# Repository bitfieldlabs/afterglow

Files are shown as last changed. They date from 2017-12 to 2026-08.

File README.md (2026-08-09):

afterglow Afterglow

AFTERGLOW is a pinball machine extension board that aims at softening the hard lamp on/off transitions which are the consequence of replacing the original incandescent bulbs with LEDs. Reproducing the original light effects is a big part of preserving a pinball game's nostalgia.

It currently works with Williams WPC, Williams System 11, Data East and probably also with Sega games. The basic principle involves resampling of the original lamp matrix signals at a higher frequency. This allows for PWM LED dimming with additional brightness steps.

The resampled signal is output via MOSFETs, allowing for direct connection of your pinball machine's lamp matrix.

Make sure to check the wiki for detailed information and instructions.

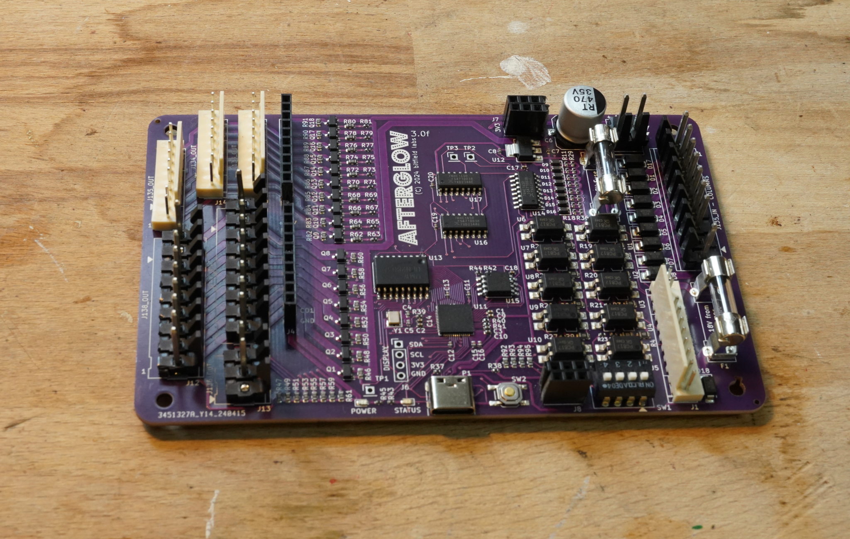
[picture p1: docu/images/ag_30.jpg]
afterglow Afterglow PCB v3.0


While the effect is hard to catch on camera, this video gives an idea:

https://github.com/bitfieldlabs/afterglow/assets/999857/57093b11-0a40-46fb-a978-5d42df743db6

## Licensing

Firmware and configuration software:
Apache License 2.0

Hardware designs:
CERN Open Hardware License - Permissive 2.0

See LICENSES/ for details

### Licensing change

As of August 2026:

- Firmware and configuration software are licensed under Apache-2.0.
- Hardware designs are licensed under CERN-OHL-P-2.0.

All contributors with copyrightable contributions
have consented to the relicensing, or their
contributions have been replaced.

### Quick guide to the board revisions

#### All in one
* *PCB v3.0*<br/>This is the newest board built around the RP2040. Supports WPC, Data East, Sys11, Whitestar, S.A.M.<br/>Supports hats, allowing for different ouput connectors, modding ports, displays etc.<br/>Input protection using optocouplers.<br/>Check the [folder's readme](https://github.com/bitfieldlabs/afterglow/tree/master/afterglow_pcb_v30) for more details.

#### WPC, WPC-95, System 11, Data East, Sega
* *PCB v1.3*<br/>This is the *preferred board revision* for these games.<br/>Dedicated power input (+18V, Ground) must be connected separately to power driver board
* *PCB v1.4*<br/>Except for power input exactly the same as revision 1.3<br/>+18V taken from column input.<br/>⚠ Ground must still be connected to the PDB! Failure to do so will damage the board!
* *PCB v1.5*<br/>Same as v1.4, but using a one-sided PCB. This should be easier/cheaper for automated production than v1.4.

#### Stern Whitestar (and possibly S.A.M.)
* *PCB v2.1* Dedicated board which will only work with Stern Whitestar and possibly S.A.M. games

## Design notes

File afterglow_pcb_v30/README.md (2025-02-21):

# Afterglow PCB v3.0

This is the newest generation of afterglow boards for the switched playfield lamps (not the GI), supporting WPC, Data East, System 11 and Stern Whitestar/S.A.M. games.

## What's new

The new board is based on the RP2040 microprocessor. It is more robust than previous versions and it supports hats!

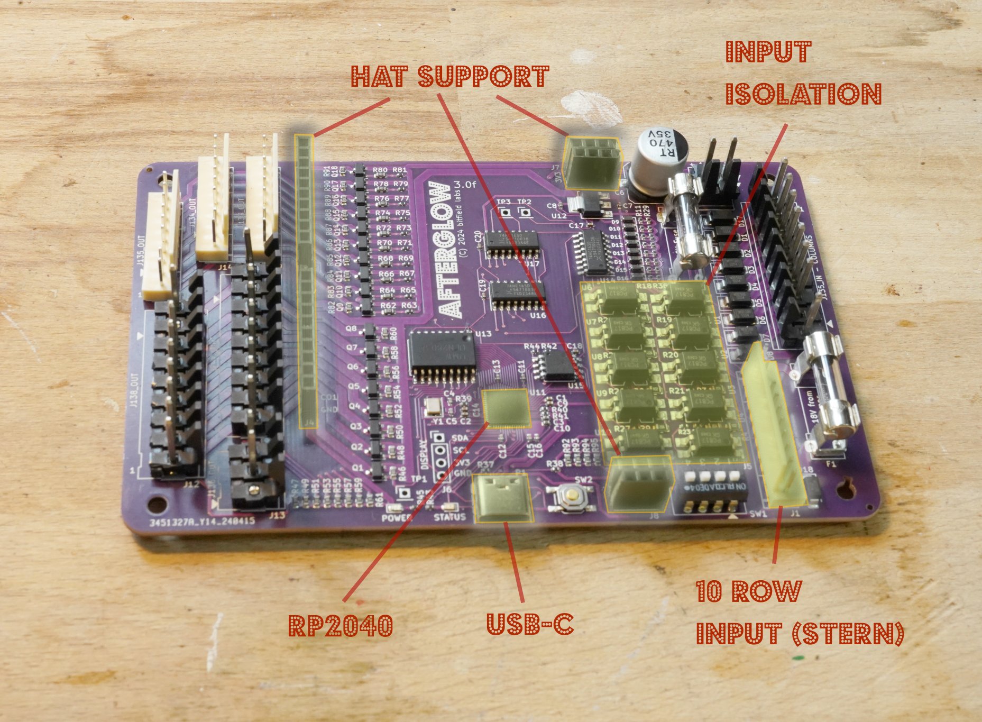
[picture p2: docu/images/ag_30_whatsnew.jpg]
afterglow Afterglow PCB v3.0 What's New


## Production
This board is designed for automated PCB production and assembly. The [gerber directory](https://github.com/bitfieldlabs/afterglow/tree/master/afterglow_pcb_v30/gerber) contains production files for [JLCPCB](https://jlcpcb.com/).

Components were chosen based on availability and price.

The connectors and some other parts are currently not included in the assembly files.

## Firmware
The RP2040 firmare is available in the [afterglow_rp2040_firmware](https://github.com/bitfieldlabs/afterglow/tree/master/afterglow_rp2040_firmware) directory. 

### Building the firmware
The firmware is built using [Visual Studio Code](https://code.visualstudio.com/) with [platformio](https://platformio.org/). You may need to install the wizio library manually (PIO Home->Advanced Installation, enter https://github.com/maxgerhardt/wizio-pico).
It uses [wizio-pico](https://github.com/maxgerhardt/wizio-pico) as a baremetal framework.

### Updating the firmware
There is also a [prebuilt binary UF2 file](https://github.com/bitfieldlabs/afterglow/tree/master/afterglow_rp2040_firmware/firmware_binary_uf2) available for direct upload to the chip. Push the boot select button SW2 when powering up and a mass storage device should appear on your computer. Just copy over the firmware uf2 file.

## Hats
The board supports the connection of hats, extending the functionality to other games, for debugging, modding etc.

### The debugger's hat
The [debugger's hat PCB project](https://github.com/bitfieldlabs/afterglow/tree/master/afterglow_pcb_v30/hat_debug) just visualizes the lamp matrix with LEDs and adds a connector for an I2C OLED display.

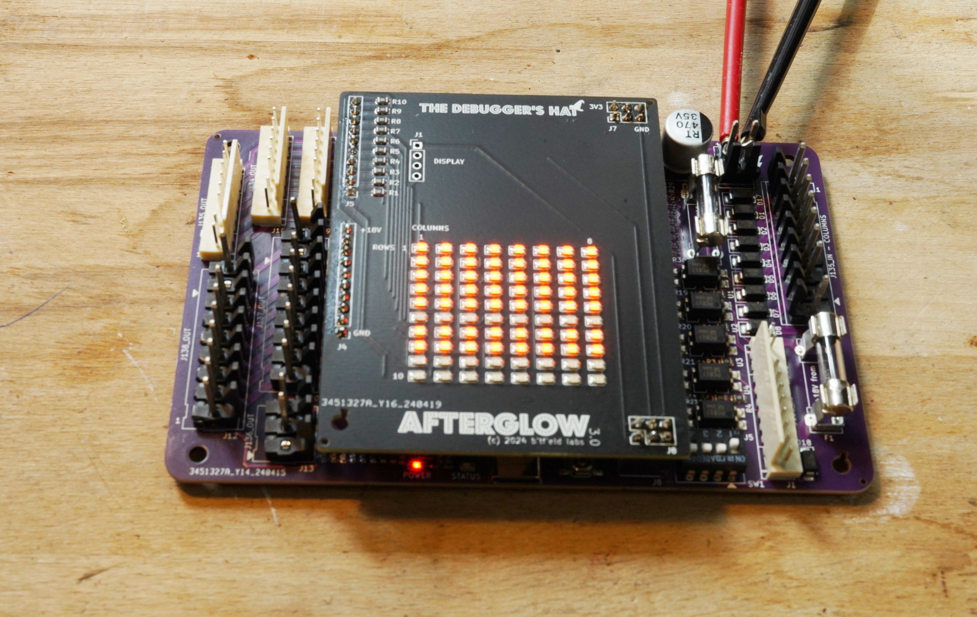
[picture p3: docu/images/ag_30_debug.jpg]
afterglow Afterglow PCB v3.0 Debugger's hat


### The pin bender hat
The [pin bender hat](https://github.com/bitfieldlabs/afterglow/tree/master/afterglow_pcb_v30/hat_stern_de_sys11) adds connectors for direct hookup of Stern Whitestar/S.A.M games as well as Data East and System 11 machines.

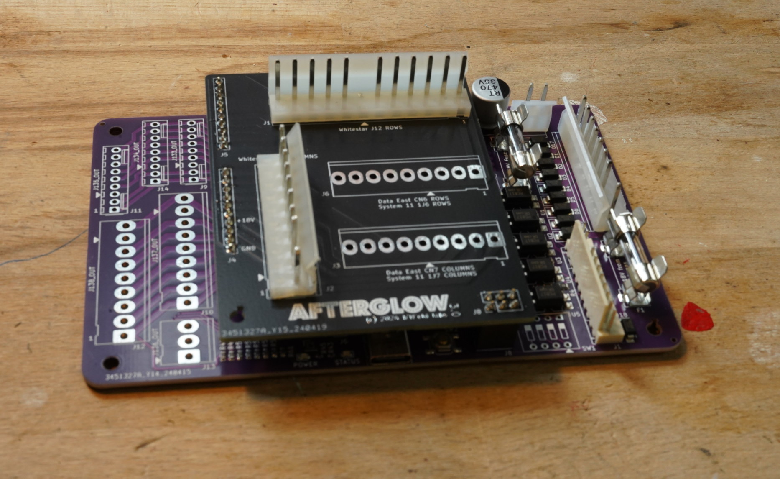
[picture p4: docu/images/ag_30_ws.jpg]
afterglow Afterglow PCB v3.0 Pin Bender hat


### Creating new hats
There is a [template kicad project](https://github.com/bitfieldlabs/afterglow/tree/master/afterglow_pcb_v30/hat_template) which can be used as a starting point for new hats.

## Files

* Schematic Afterglow PCB v3.0 Schematic
* BOM Afterglow PCB v3.0 BOM

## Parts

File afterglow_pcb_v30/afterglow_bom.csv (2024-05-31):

Reference | Value | Datasheet | Footprint | Qty | DNP
C1,C2,C9,C11,C12,C13,C14,C15,C16,C17,C19,C20,C21 | 100n | ~ | Capacitor_SMD:C_0402_1005Metric | 13
C3,C10 | 1u | ~ | Capacitor_SMD:C_0402_1005Metric | 2
C4,C5 | 22p | ~ | Capacitor_SMD:C_0402_1005Metric | 2
C6 | 470uF | ~ | Capacitor_SMD:C_Elec_10x10.2 | 1
C7,C8 | 1uF |  | Capacitor_SMD:C_0402_1005Metric | 2
C18 | 0.1 |  | Capacitor_SMD:C_0402_1005Metric | 1
D1,D2,D3,D4,D5,D6,D7,D8,D17,D18 | RB080 | ~ | Diode_SMD:D_SMA | 10
D9,D10,D11,D12,D13,D14,D15,D16 | 3.0V | ~ | Diode_SMD:D_SOD-323 | 8
F1,F2 | 5A SB |  | Fuse:Fuseholder_Clip-5x20mm_Schurter_OG_Lateral_P15.00x5.00mm_D1.3mm_Horizontal | 2
J1 | J133_IN_R | ~ | Connector_Molex:Molex_KK-254_AE-6410-11A_1x11_P2.54mm_Vertical | 1
J2 | J137_IN_C |  | Connector_Molex:Molex_KK-396_5273-09A_1x09_P3.96mm_Vertical | 1
J3 | Conn_Power | ~ | Connector_Molex:Molex_KK-396_5273-02A_1x02_P3.96mm_Vertical | 1
J4,J5 | Conn_01x10_Pin | ~ | Connector_PinSocket_2.54mm:PinSocket_1x10_P2.54mm_Vertical | 2
J6 | Conn_01x04_Socket | ~ | Connector_PinHeader_2.54mm:PinHeader_1x04_P2.54mm_Vertical | 1
J7,J8 | Conn_02x03_Odd_Even | ~ | Connector_PinSocket_2.54mm:PinSocket_2x03_P2.54mm_Vertical | 2
J9 | J133_OUT_R |  | Connector_Molex:Molex_KK-254_AE-6410-09A_1x09_P2.54mm_Vertical | 1
J10 | J137_OUT_C |  | Connector_Molex:Molex_KK-396_5273-09A_1x09_P3.96mm_Vertical | 1
J11 | J134_OUT_R |  | Connector_Molex:Molex_KK-254_AE-6410-09A_1x09_P2.54mm_Vertical | 1
J12 | J138_OUT_C |  | Connector_Molex:Molex_KK-396_5273-09A_1x09_P3.96mm_Vertical | 1
J13 | 136_OUT_C |  | Connector_Molex:Molex_KK-396_5273-03A_1x03_P3.96mm_Vertical | 1
J14 | J135_OUT_R |  | Connector_Molex:Molex_KK-254_AE-6410-09A_1x09_P2.54mm_Vertical | 1
P1 | USB_C_Receptacle_USB2.0_14P | https://www.usb.org/sites/default/files/documents/usb_type-c.zip | Connector_USB:USB_C_Receptacle_HRO_TYPE-C-31-M-12 | 1
PWR_LED1,ST_LED1 | LED | ~ | LED_SMD:LED_0603_1608Metric | 2
Q1,Q2,Q3,Q4,Q5,Q6,Q7,Q8 | AO3401A | http://www.aosmd.com/pdfs/datasheet/AO3401A.pdf | Package_TO_SOT_SMD:SOT-23 | 8
Q9,Q10,Q11,Q12,Q13,Q14,Q15,Q16,Q17,Q18 | AO3400A | http://www.aosmd.com/pdfs/datasheet/AO3400A.pdf | Package_TO_SOT_SMD:SOT-23 | 10
R1,R2,R3,R4,R5,R6,R7,R8,R9,R10,R11,R12,R13,R14,R15,R16,R17,R18,R19,R20,R21,R22,R23,R24,R25,R26,R27,R28,R29,R30,R31,R32,R33,R34,R35,R36,R39,R42,R43,R45 | 1k | -- mixed values -- | -- mixed values -- | 40
R37,R38 | 5k1 | ~ | Resistor_SMD:R_0402_1005Metric | 2
R40,R41 | 27 | ~ | Resistor_SMD:R_0402_1005Metric | 2
R44,R47,R49,R51,R53,R55,R57,R59,R61,R63,R65,R67,R69,R71,R73,R75,R77,R79,R81,R82,R83,R84,R85,R86,R87,R88,R89,R90,R91,R92,R93,R94,R95 | 10k | -- mixed values -- | -- mixed values -- | 33
R46,R48,R50,R52,R54,R56,R58,R60 | 2k |  | Resistor_SMD:R_0603_1608Metric | 8
R62,R64,R66,R68,R70,R72,R74,R76,R78,R80 | 220 |  | Resistor_SMD:R_0603_1608Metric | 10
R96 | 200mOhm | ~ | Resistor_SMD:R_2512_6332Metric | 1
SW1 | CFG |  | Button_Switch_THT:SW_DIP_SPSTx04_Slide_9.78x12.34mm_W7.62mm_P2.54mm | 1
SW2 | SW_Push | ~ | Button_Switch_SMD:SW_SPST_SKQG_WithStem | 1
TP1,TP2,TP3 | TestPoint | ~ | Connector_PinHeader_2.54mm:PinHeader_1x01_P2.54mm_Vertical | 3
U1,U2,U3,U4,U5,U6,U7,U8,U9,U10 | PC817 | http://www.soselectronic.cz/a_info/resource/d/pc817.pdf | Package_DIP:SMDIP-4_W9.53mm | 10
U11 | RP2040 |  | Package_DFN_QFN:QFN-56-1EP_7x7mm_P0.4mm_EP3.2x3.2mm_ThermalVias | 1
U12 | NCP1117-3.3_SOT223 | http://www.onsemi.com/pub_link/Collateral/NCP1117-D.PDF | Package_TO_SOT_SMD:SOT-223-3_TabPin2 | 1
U13 | ULN2803A |  | Package_SO:SOIC-18W_7.5x11.6mm_P1.27mm | 1
U14,U16,U17 | 74LS165 |  | Package_SO:SOIC-16_3.9x9.9mm_P1.27mm | 3
U15 | W25Q32JVSS | http://www.winbond.com/resource-files/w25q32jv%20revg%2003272018%20plus.pdf | Package_SO:SOIC-8_5.23x5.23mm_P1.27mm | 1
U18 | INA181A1 | http://www.ti.com/lit/ds/symlink/ina181.pdf | Package_TO_SOT_SMD:SOT-23-6 | 1
Y1 | Crystal_GND24_Small | ~ | Crystal:Crystal_SMD_3225-4Pin_3.2x2.5mm | 1

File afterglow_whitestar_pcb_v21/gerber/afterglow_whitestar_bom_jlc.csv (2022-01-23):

Comment | Designator | Footprint | LCSC Part #
0.33 | C2 | C_0805_2012Metric_Pad1.18x1.45mm_HandSolder | C1740
0.1 | C3,C4,C5 | C_0805_2012Metric_Pad1.18x1.45mm_HandSolder | C28233
WS2812B | D1 | LED_WS2812B-PLCC4 | C2761795
4.7V | D2,D3,D4,D5,D6,D7,D8,D9 | D_SOD-323_HandSoldering | C391551
1k | R1,R2,R3,R4,R5,R6,R7,R8,R9,R10,R11,R12,R13,R14,R15,R16,R17,R18,R19,R20,R21,R22,R23,R24 | R_0805_HandSoldering | C95781
10k | R25,R27,R28,R29,R30,R31,R32,R33,R34,R44,R46,R48,R50,R52,R54,R56,R58,R59,R60,R61,R62,R63,R64,R65,R66,R67,R69,R70,R71 | R_0805_HandSoldering | C84376
220 | R26,R43,R45,R47,R49,R51,R53,R55,R57,R68 | R_0805_HandSoldering | C17557
2k | R35,R36,R37,R38,R39,R40,R41,R42 | R_0805_HandSoldering | C17604
74LS165 | U1,U2 | SOIC-16_3.9x9.9mm_Pitch1.27mm | C5613
74HC595 | U5,U6 | SOIC-16_3.9x9.9mm_Pitch1.27mm | C5947
ULN2803A | U7 | SOIC-18W_7.5x11.6mm_Pitch1.27mm | C845537

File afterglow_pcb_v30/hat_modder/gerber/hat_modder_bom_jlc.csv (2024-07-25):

Comment | Designator | Footprint | LCSC Part Number
LED | D1,D2,D3,D4 | LED_0805_2012Metric | C2296
Conn_02x03_Odd_Even | J2,J3 | PinHeader_2x03_P2.54mm_Vertical | C92272
1k | R1,R6,R7,R8,R9 | R_0805_2012Metric | C17513
220 | R2,R3,R4,R5 | R_0805_2012Metric | C17557
74HC244 | U1 | TSSOP-20_4.4x6.5mm_P0.65mm | C6835
74HC595 | U2 | SO-16_3.9x9.9mm_P1.27mm | C5947
PC817 | U3,U4,U5,U6 | SMDIP-4_W9.53mm | C3025164

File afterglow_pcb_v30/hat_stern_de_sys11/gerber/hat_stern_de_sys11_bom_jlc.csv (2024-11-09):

Comment | Designator | Footprint | LCSC Part Number
ROW OUT | J1 | Molex_KK-396_5273-12A_1x12_P3.96mm_Vertical | C10589
COLUMN OUT | J2 | Molex_KK-396_5273-10A_1x10_P3.96mm_Vertical | C10587
Conn_01x09_Pin | J3,J6 | Molex_KK-396_5273-09A_1x09_P3.96mm_Vertical | C10586
Conn_01x10_Pin | J4,J5 | PinHeader_1x10_P2.54mm_Vertical | C5156617
Conn_02x03_Odd_Even | J7,J8 | PinHeader_2x03_P2.54mm_Vertical | C18905882

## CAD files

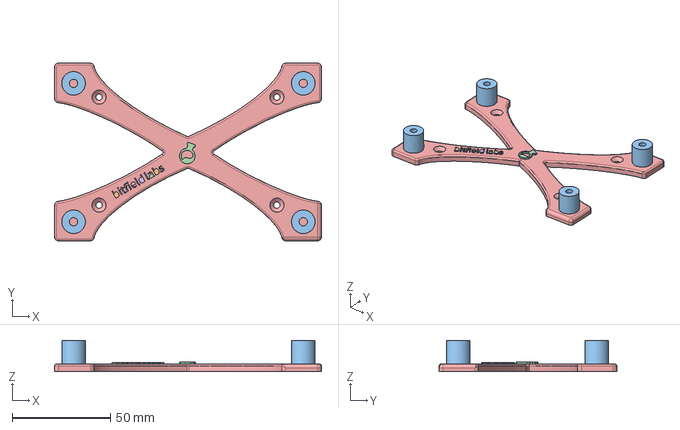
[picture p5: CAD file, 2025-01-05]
accessories/ag_14_to_30_holder_generic_insert_higher.step
136.0 x 90.5 x 16.0 mm

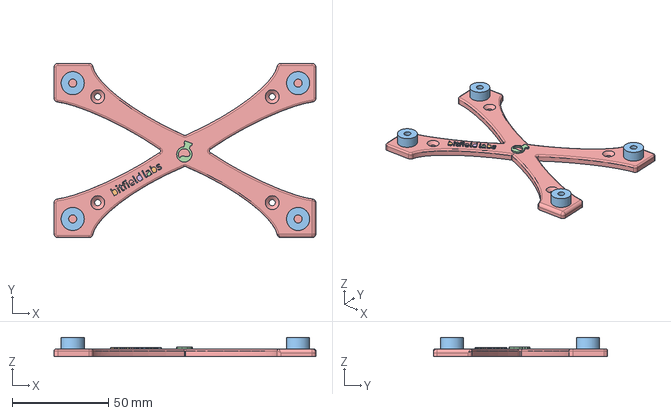
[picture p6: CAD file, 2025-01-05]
accessories/ag_14_to_30_holder_generic_insert.step
136.0 x 90.5 x 10.0 mm

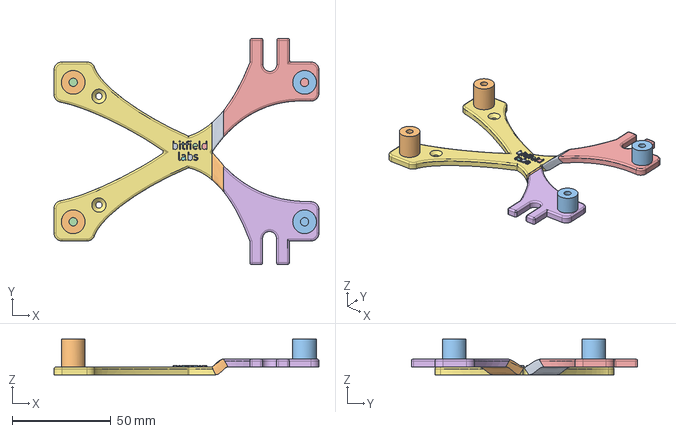
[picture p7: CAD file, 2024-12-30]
accessories/ag_14_to_30_holder_wpc_insert.step
134.0 x 114.5 x 18.0 mm

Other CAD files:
accessories/ag_14_to_30_holder_generic_screw_higher.step
accessories/ag_14_to_30_holder_generic_screw.step
accessories/ag_14_to_30_holder_wpc_screw.step
accessories/ag_14_to_30_holder_generic_insert.stl
accessories/ag_14_to_30_holder_generic_insert_higher.stl
accessories/ag_14_to_30_holder_generic_screw.stl
accessories/ag_14_to_30_holder_generic_screw_higher.stl
accessories/ag_14_to_30_holder_wpc_insert.stl
accessories/ag_14_to_30_holder_wpc_screw.stl

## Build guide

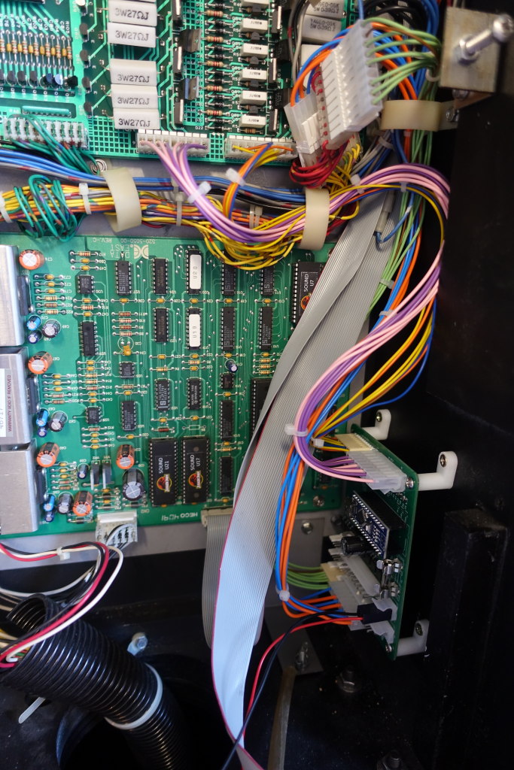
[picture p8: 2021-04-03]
docu/images/data_east_installation_2.jpg

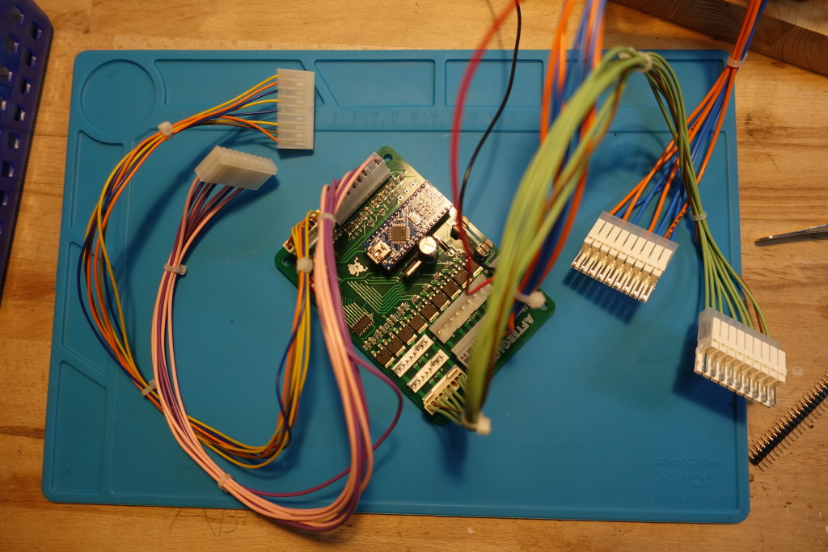
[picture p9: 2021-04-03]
docu/images/data_east_installation_1.jpg

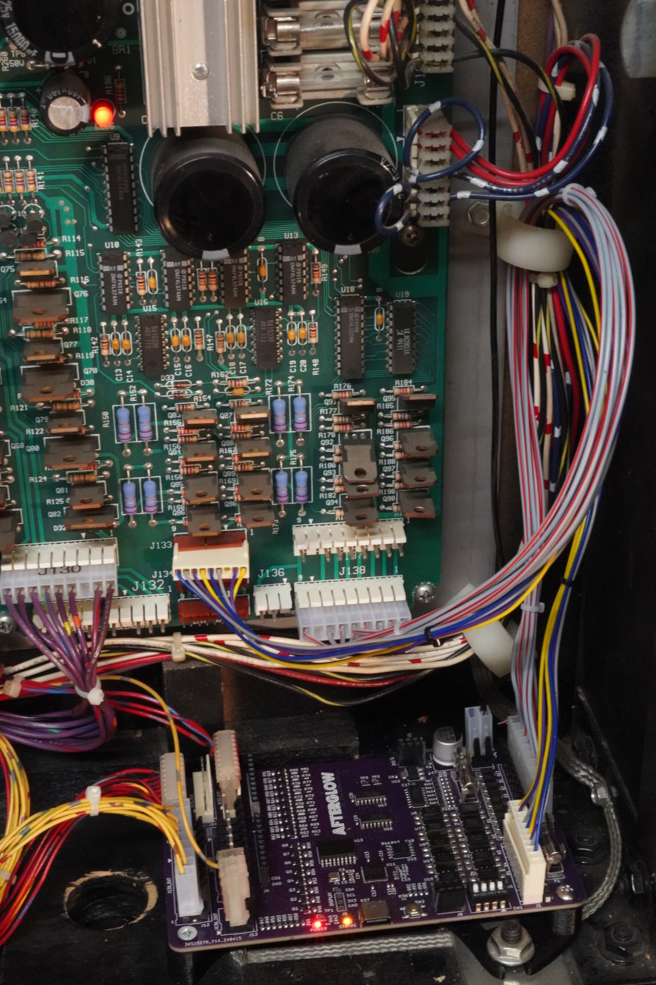
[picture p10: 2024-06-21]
docu/images/ag_30_installed_wpc.jpg

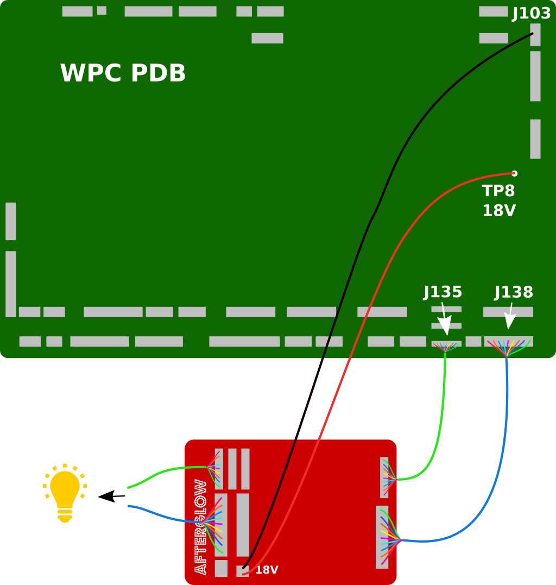
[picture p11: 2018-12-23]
docu/afterglow_installation.png

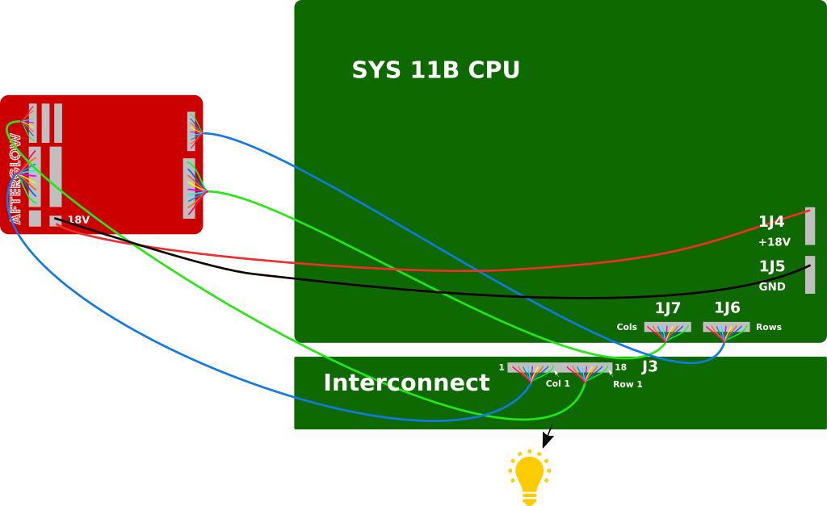
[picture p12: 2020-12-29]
docu/afterglow_installation_sys11.png

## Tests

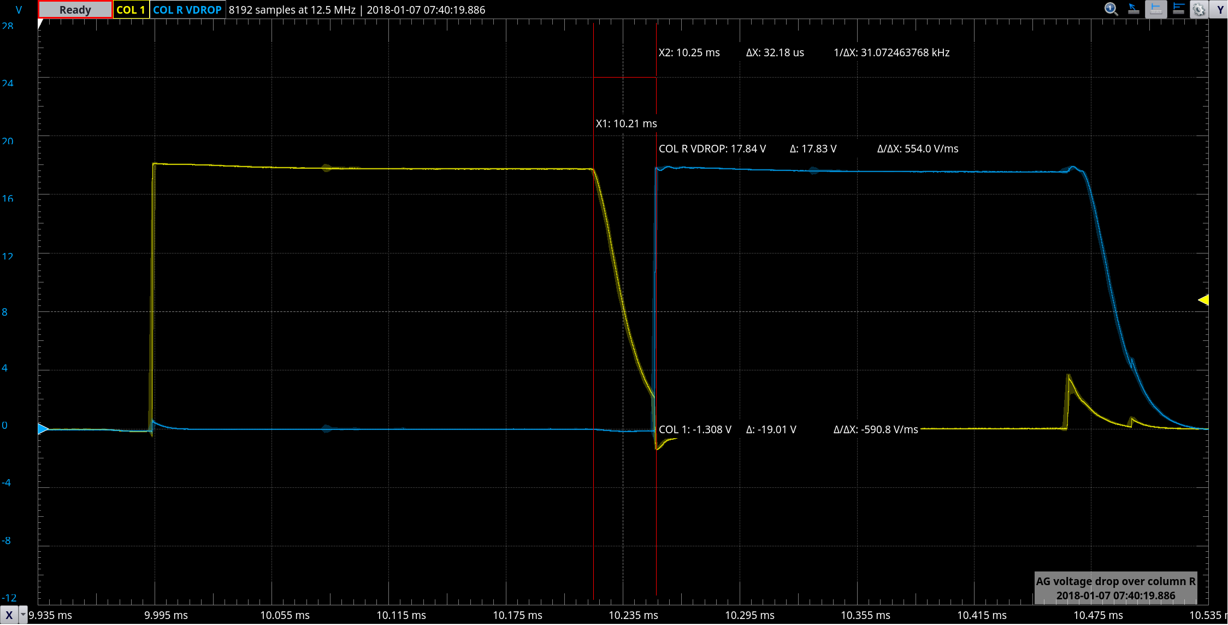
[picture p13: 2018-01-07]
scopes/AG/col1_col2_col2_testmode.png

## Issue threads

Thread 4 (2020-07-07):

STM32 Version

madnat, 2020-07-07:
Hi there - enjoyed following your work on Afterglow and AGGI.

Is there a technical reason for splitting the LED functions between 2 different boards?  I assume it is a speed issue for the Arduino Nano?

Discussing with Stumblor, interested to see if creating a STM32 version of this could enable a combined board to manage all LED's on a machine?  STM32 is technically a more superior processor (in every way I think?), and should run the same code as an Arduino.  It is also more power efficient I believe.

I have started to map your schematic of Afterglow to a STM32 version (I use Eagle however), very happy to publish to a new fork - if it would be helpful to work on this together?

With a more powerful processor the scope for extending capability, e.g. support additional addressable LED strings could be very cool (i.e. support SK6812 controllers - sync lighting or trigger new light effect based existing lamp events).

Could be getting crazy here - but also thought adding a WiFi module would then enable configuration on the fly rather than an external app.  No doubt that would need some additional memory/SD.  We could learn a lot from the PIN2DMD project.

Hope these suggestions/offer is helpful

Closed 2021-01-02.

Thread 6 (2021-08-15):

add game jokerz sys11b

ledu205, 2021-08-15:
[games.zip](https://github.com/bitfieldlabs/afterglow/files/6988503/games.zip)

config for jokerz pinball work good with pcb 1.4

bitfieldlabs, 2021-08-16:
Tanks! Pushed to repository.

Closed 2021-08-16.

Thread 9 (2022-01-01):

Errors on 1.4 PCB

JustinRudebaugh, 2022-01-01:
First off - Excellent project! I've been reading through everything I can here and on pinball forums.  I've ordered a batch of these to assemble and found a couple issues, and a question after exporting the BOM via KiCAD (for use with Partsbox).

-R67 is listed as "18v COL".  I see note in wiki about the 18V columns, but would this be a jumper or resistor in the R67 position? If it's a resistor, what's the value?
-J1 is listed in BOM as J137_IN_C, but silkscreen is J138_IN_C
-J2 is listed in BOM as J133_IN_R, but silkscreen is J135_IN_R
-D1, D10, D11, D12, D13, D14, D15, D16, and D17 is not on the silkscreen

Thank you!

bitfieldlabs, 2022-01-01:
Thanks for the feedback. I will need to make adjustments to the BOM later.

R67 is a zero Ohm resistor. It can be populated as a wire bridge. It is only needed when feeding the +18V from the columns and can be left unpopulated when supplying +18V via J3.

J137 and J138 are connected to the same lines. The same is true for the J133, J134 and J135 connectors. The labels are used a bit inconsistently in the schematic and silkscreen. On the silkscreen I wanted to make clear where to connect to easiest.

Somehow my Kicad footprint for the Schottky diodes doesn't have a proper silkscreen layer. I need to fix that.

Be also aware that I've had several reports of damaged v1.4 boards when people forgot to connect the ground line. It's a design flaw of this +18V from columns design. Personally I prefer the v1.3 board as I also don't mind connecting both +18V and GND to the PPD.

bitfieldlabs, 2022-01-02:
Fixed silkscreening issues with [5ce20851](https://github.com/bitfieldlabs/afterglow/commit/5ce20851aaa8b1ce0ea9a661658f488daa178507).
R67 documented in BOM.

Closed 2022-01-02.

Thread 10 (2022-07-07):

Afterglow version using atmega328p DIP version

bzhmaddog, 2022-07-07:
Not a bug but I was thinking of using an atmega328p dip chip (the one on the original arduino uno) instead of a nano daughter board.
It is basically the same chip as the one on the nano except for A6 and A7 io missing but thoses are not used on afterglow design af far as I can tell.
The chip would fit in the area where nano goes and just requires a crystal and two caps plus a 2x3 pin header for ICSP programming.

bitfieldlabs, 2022-07-08:
Yes, that is for sure feasible. You will lose the USB interface to the configuration software, but that may not be an issue to many. If the part crisis would allow it, you could also use the small SMD chip.

bzhmaddog, 2022-07-08:
I forked your repository and started working on it (v1.3 for now). I am not a big fan of SMD since it requires extra effort for soldering. As for the usb I will provide an ICSP header which is sure less conveniant than usb but I think people who are ready to flash a sketch file through arduino ide will probably also have some arduino lying around to use as programmer

Closed 2024-02-03.

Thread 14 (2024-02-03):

Wrong label for pin1 of J138

bzhmaddog, 2024-02-03:
The 'documentation' states
Board revision 1.3 has the J138 OUT connector pin 1 labelled on the wrong side! The pin labelled "1" is actually pin 9.

But what is the action required to mitigate the issue ? just swap the connector orrientation  ? or swap the wires on the harness ?

bitfieldlabs, 2024-02-04:
No action needed really. The original J138 connectors can be used. It's just that pin 1 is on the other side of the connector, where it should be. The label is just confusing as it suggests that the connector must be the wrong way round.

bzhmaddog, 2024-02-04:
I see so it is only the label that is wrong but not the traces on the board.

Additionnaly I am wondering why tapping in the 18V to generate the 5V? It is only used to power the Arduino and the few ICs right ? So the LM7805 must be quite hot dropping from 18V to 5V.
Why not using a 12V input ? not enough Amps ? Sorry if it is a dumb question I am not an electronical engineer.

bzhmaddog, 2024-02-04:
I am starting to wonder if that board is compatible with System 11a. The key pins on J6/J7 on my PDB does not match.

https://imgur.com/a/R12S2Hx

bitfieldlabs, 2024-02-04:
The LM7805 doesn't get hot as the 5V side is using only very little power. The 18V are needed to drive the lamp matrix, so it makes sense to use it for the 5V regulator as well.

bitfieldlabs, 2024-02-04:
The board should be fine in Sys11a games, I have personally only tested with Sys11b.
The keys are in a different place than on WPC, you just need to make sure you connect col 1 on the output of the driver board to col 1 on the AG input etc.
https://github.com/bitfieldlabs/afterglow/wiki/Instructions#system-11-installation

bzhmaddog, 2024-02-04:
I see.
My bad I didn't read the schematic correctly. Obviously the 18V is needed since the board hook into the original lines
So I guess I have to make and adapter to make the rows and cols match.

Thx

Closed 2024-02-04.

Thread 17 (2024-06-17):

V3.0 - Fuse holders and J1

vikbez, 2024-06-17:
Hello;

Was about to order the new version to try it :)

I have some questions: I found `J1` to match either:
- [LCSC C22451132](https://www.lcsc.com/product-detail/Wire-To-Board-Connector_DLL-2510-11A_C22451132.html)
- [LCSC C2982040](https://www.lcsc.com/product-detail/Wire-To-Board-Connector_HCTL-HC-2510-11A_C2982040.html)

Are these good candidates ? (only the second one available right now)

For `F1` and `F2` (fuse holders):
I just cannot find them at all. Every part I find are rotated 90deg , or have only 2 pins total:
- [90deg rotated holder](https://i.ebayimg.com/images/g/k7gAAOSw8FBbCToB/s-l1200.jpg)
- [2 pins inline holder](https://www.tancredi.it/55146-large_default/PCB-fuse-holder-for-fuses-5x20mm.jpg)

Maybe these would be more appropriate for the design as they are more easy to find ?

Thanks !

bitfieldlabs, 2024-06-18:
Hi. Yes, the J1 connectors look fine. They are not in the JLC BOM because I couldn't find an exact match for the series I am usually using.

I agree, I will have to change the fuse holders to more common ones, I just didn't get around to doing it yet.

bitfieldlabs, 2024-06-18:
These are the fuse holders I am using: https://jlcpcb.com/partdetail/Schurter-07510062/C3205391
Not on stock though.

Numiah, 2024-11-04:
For the users from Netherlands, Germany etc.
I used these :[https://www.conrad.nl/nl/p/eska-120700-120700-zekeringclip-geschikt-voor-buiszekering-5-x-20-mm-6-3-a-250-v-ac-1-stuk-s-524314.html](url)

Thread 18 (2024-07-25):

Resistor Sizes incorrect in JLCPCB BOM

Nutty-69, 2024-07-25:
Hi

JLCPCB is incorrectly sizing to 0603 in resistor row R63 - R81.

For Example it has row R82 - R91 and R63 - R81

in the same part yet the BOM has it listed separate.

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

Nutty-69, 2024-07-25:
I have found more as below.

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

bitfieldlabs, 2024-07-26:
Not sure I understand. The PCB version 3.0 uses a mix of 0402 and 0603 resistors. E.g., all even numbers between R62-R80 are 0603 resistors while the odd ones are 0402. I see them listed correctly in https://github.com/bitfieldlabs/afterglow/blob/master/afterglow_pcb_v30/gerber/afterglow_bom_jlc.csv...

bitfieldlabs, 2024-07-27:
That's weird as I have used the JLC files in the gerber folder multiple times now without such issues.

Nutty-69, 2024-07-27:
I will try it again tonight :-)

Nutty-69, 2024-07-27:
Ok Same files different outcome !! You got to love JLCPCB sometimes.

But this was easy to sort :-)

Thanks for your help.

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

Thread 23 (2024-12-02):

Leds with AfterGlow board 3.0 and 3.03 firmware

Vincz123, 2024-12-02:
Hello
-Brightness is set to 7, which is the maximum I can get with the board, and it's too dark.
if I remove the Afterglow board, the leds light up twice as much. (leds are 4smd high quality)

On my Medieval or Attack from mars in Attract Mode , the blinking works perfectly but not in the game,  the LED should be flashing but it is not and remains permanently lit.
i can reduce Glow intensity with the software but it's not good

If i compare with OCD , all of my leds is working fine by default

[AFM_MM.zip](https://github.com/user-attachments/files/17981836/AFM_MM.zip)

Thanks if you have any fix

Vincz123, 2024-12-02:
here is a short video in attract mode and when i start a game
[Uploading IMG_1416.zip…]()

Vincz123, 2024-12-02:
[IMG_1416.zip](https://github.com/user-attachments/files/17982011/IMG_1416.zip)
here is a short video in attract mode and when i start a game

bitfieldlabs, 2024-12-02:
Is the AfM recording from attract mode only? Or should I see the in-game issue?

Vincz123, 2024-12-02:
Only attract mode

bitfieldlabs, 2024-12-02:
And the MM recording appears to be empty.

bitfieldlabs, 2024-12-02:
The AfM replay looks nice and bright on my test matrix. But it's of course hard to tell without comparison.

bitfieldlabs, 2024-12-04:
I have tested the board in a Medieval Madness game today and couldn't spot any obvious issues.

Vincz123, 2024-12-04:
With different boards and different pinballs i have this problem.
Which leds did you use? Mine are probably anti ghosting but as i said the same leds on my Lotr and OCD board works fine by default

bitfieldlabs, 2024-12-04:
I don't know what LEDs are in that MM, it wasn't mine. I have tried the board with many different LEDs though, and while you can see some differences in the glow behavior, it's not that big.

bitfieldlabs, 2024-12-04:
I would be really curious to get one of your LEDs for testing, if possible.

bitfieldlabs, 2024-12-09:
Other things to try:
- How is the brightness in pass-through mode (DIP switch 4 on)?
- Supply +18V directly instead taking it from the columns

Vincz123, 2024-12-09:
I use the +18V directly from the driver board at TP102, I've never tried it from the columns.
I'll test DIP4 later

Vincz123, 2024-12-09:
if i only open DIP4 , it's much better for brightness intensity and flashing when I play
What is the difference with DIP4 ?

bitfieldlabs, 2024-12-09:
Pass-through mode replicates the original input signal to the output. It should look like without the AG board inbetween.

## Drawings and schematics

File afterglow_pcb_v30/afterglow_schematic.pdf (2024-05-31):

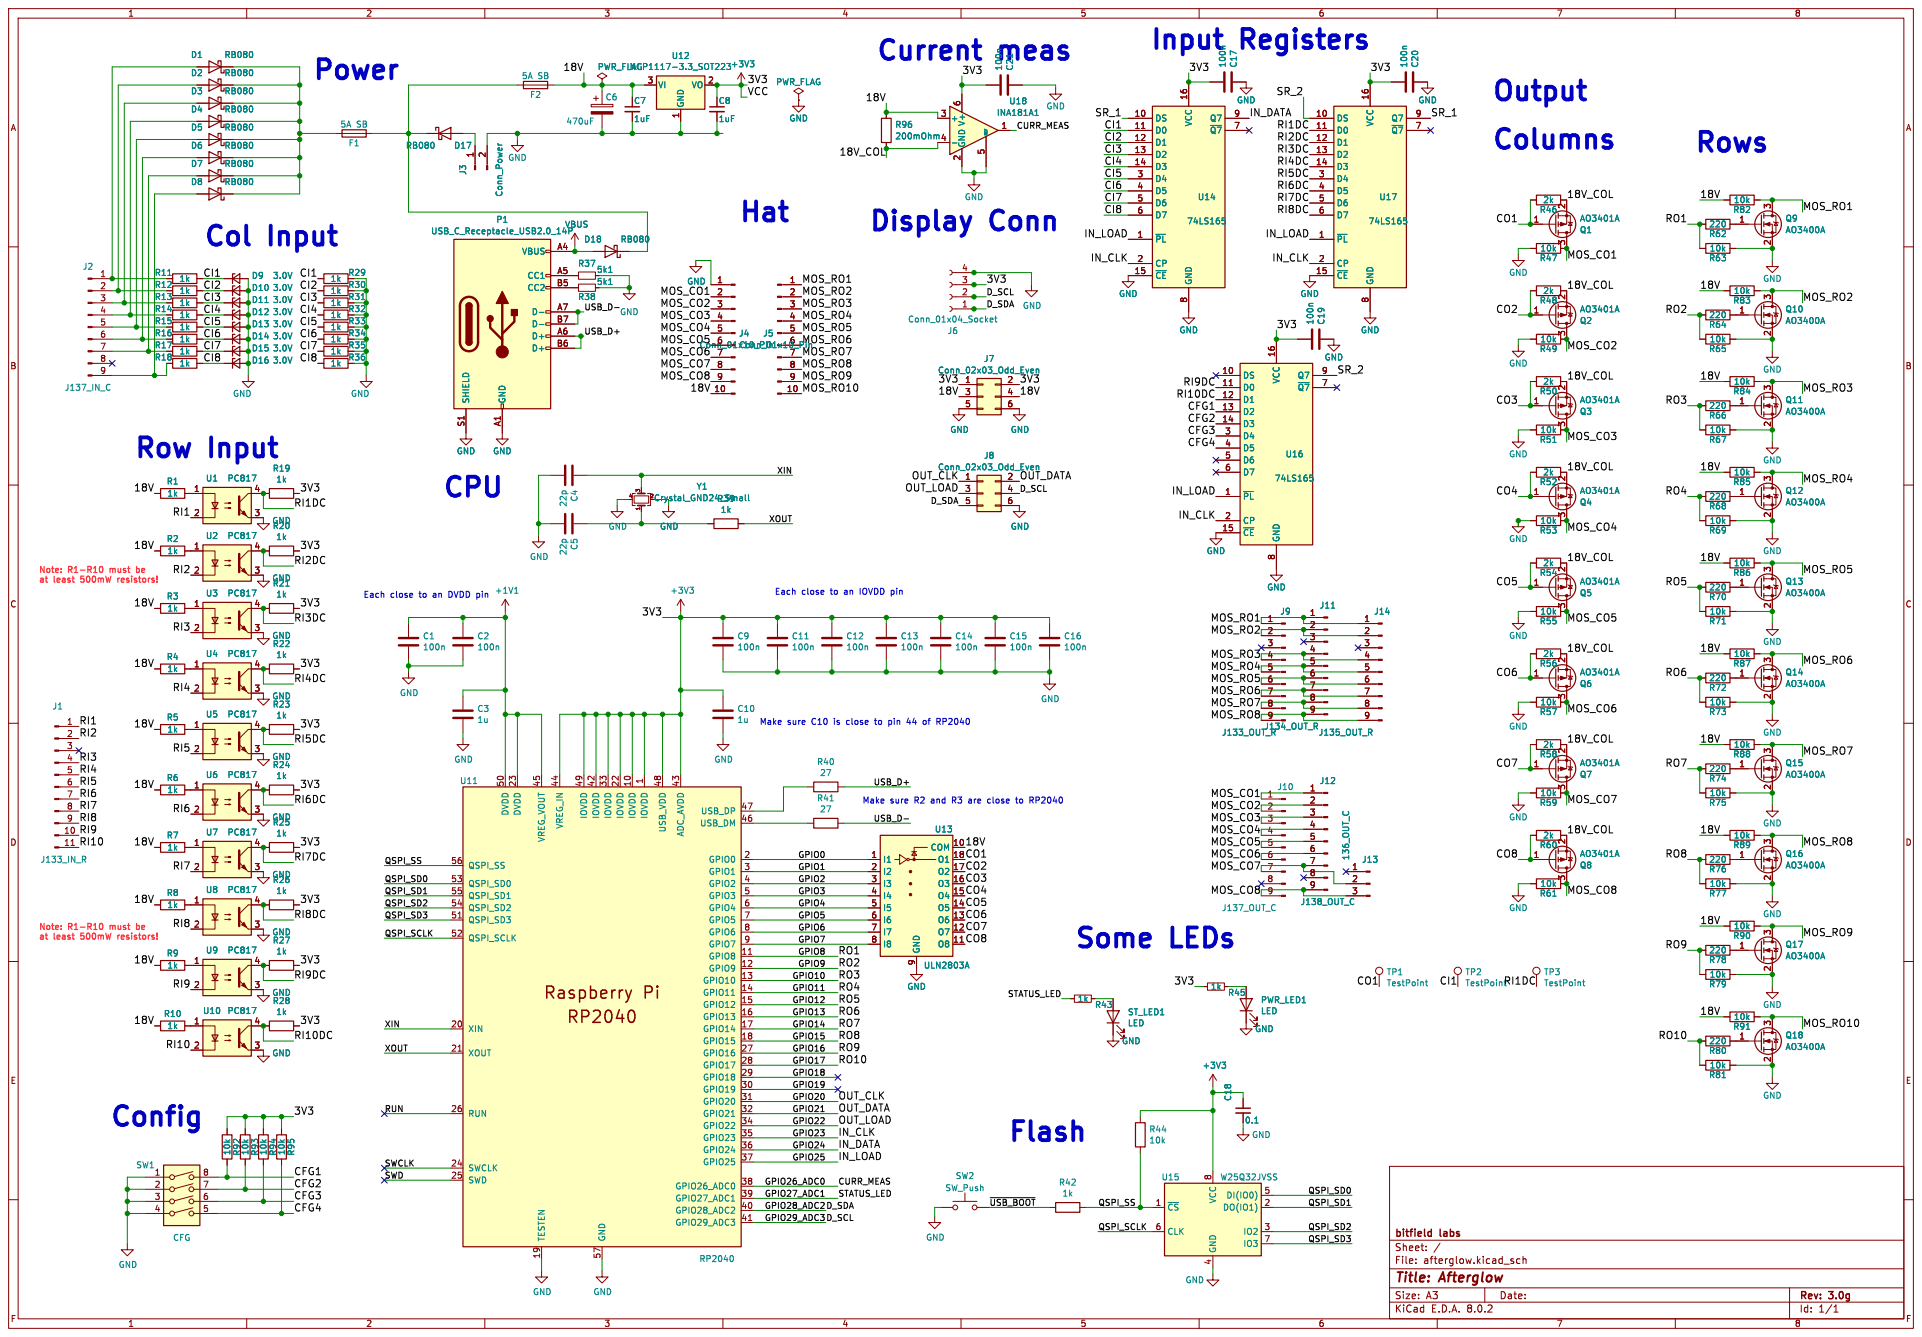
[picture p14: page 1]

Input Registers Current meas

8 Q7 9 GND GND 100n C19 GND GND

Each close to an IOVDD pin

Make sure R2 and R3 are close to RP2040 Make sure C10 is close to pin 44 of RP2040 Config

1 IOVDD 10 GPIO8 11 GPIO9 12 GPIO10 13 GPIO11 14 GPIO12 15 GPIO13 16 GPIO14 17 GPIO15 18 TESTEN 19 GPIO0 2 XIN 20 XOUT 21 IOVDD 22 DVDD 23 SWCLK 24 SWD 25 RUN 26 GPIO16 27 GPIO17 28 GPIO18 29 GPIO1 3 GPIO19 30 GPIO20 31 GPIO21 32 IOVDD 33 GPIO22 34 GPIO23 35 GPIO24 36 GPIO25 37 GPIO26_ADC0 38 GPIO27_ADC1 39 GPIO2 4 GPIO28_ADC2 40 GPIO29_ADC3 41 IOVDD 42 ADC_AVDD 43 VREG_IN 44 VREG_VOUT 45 USB_DM 46 USB_DP 47 USB_VDD 48 IOVDD 49 GPIO3 5 DVDD 50 QSPI_SD3 51 QSPI_SCLK 52 QSPI_SD0 53 QSPI_SD2 54 QSPI_SD1 55 QSPI_SS 56 GND 57 GPIO4 6 GPIO5 7 GPIO6 8 GPIO7 9 U11 RP2040

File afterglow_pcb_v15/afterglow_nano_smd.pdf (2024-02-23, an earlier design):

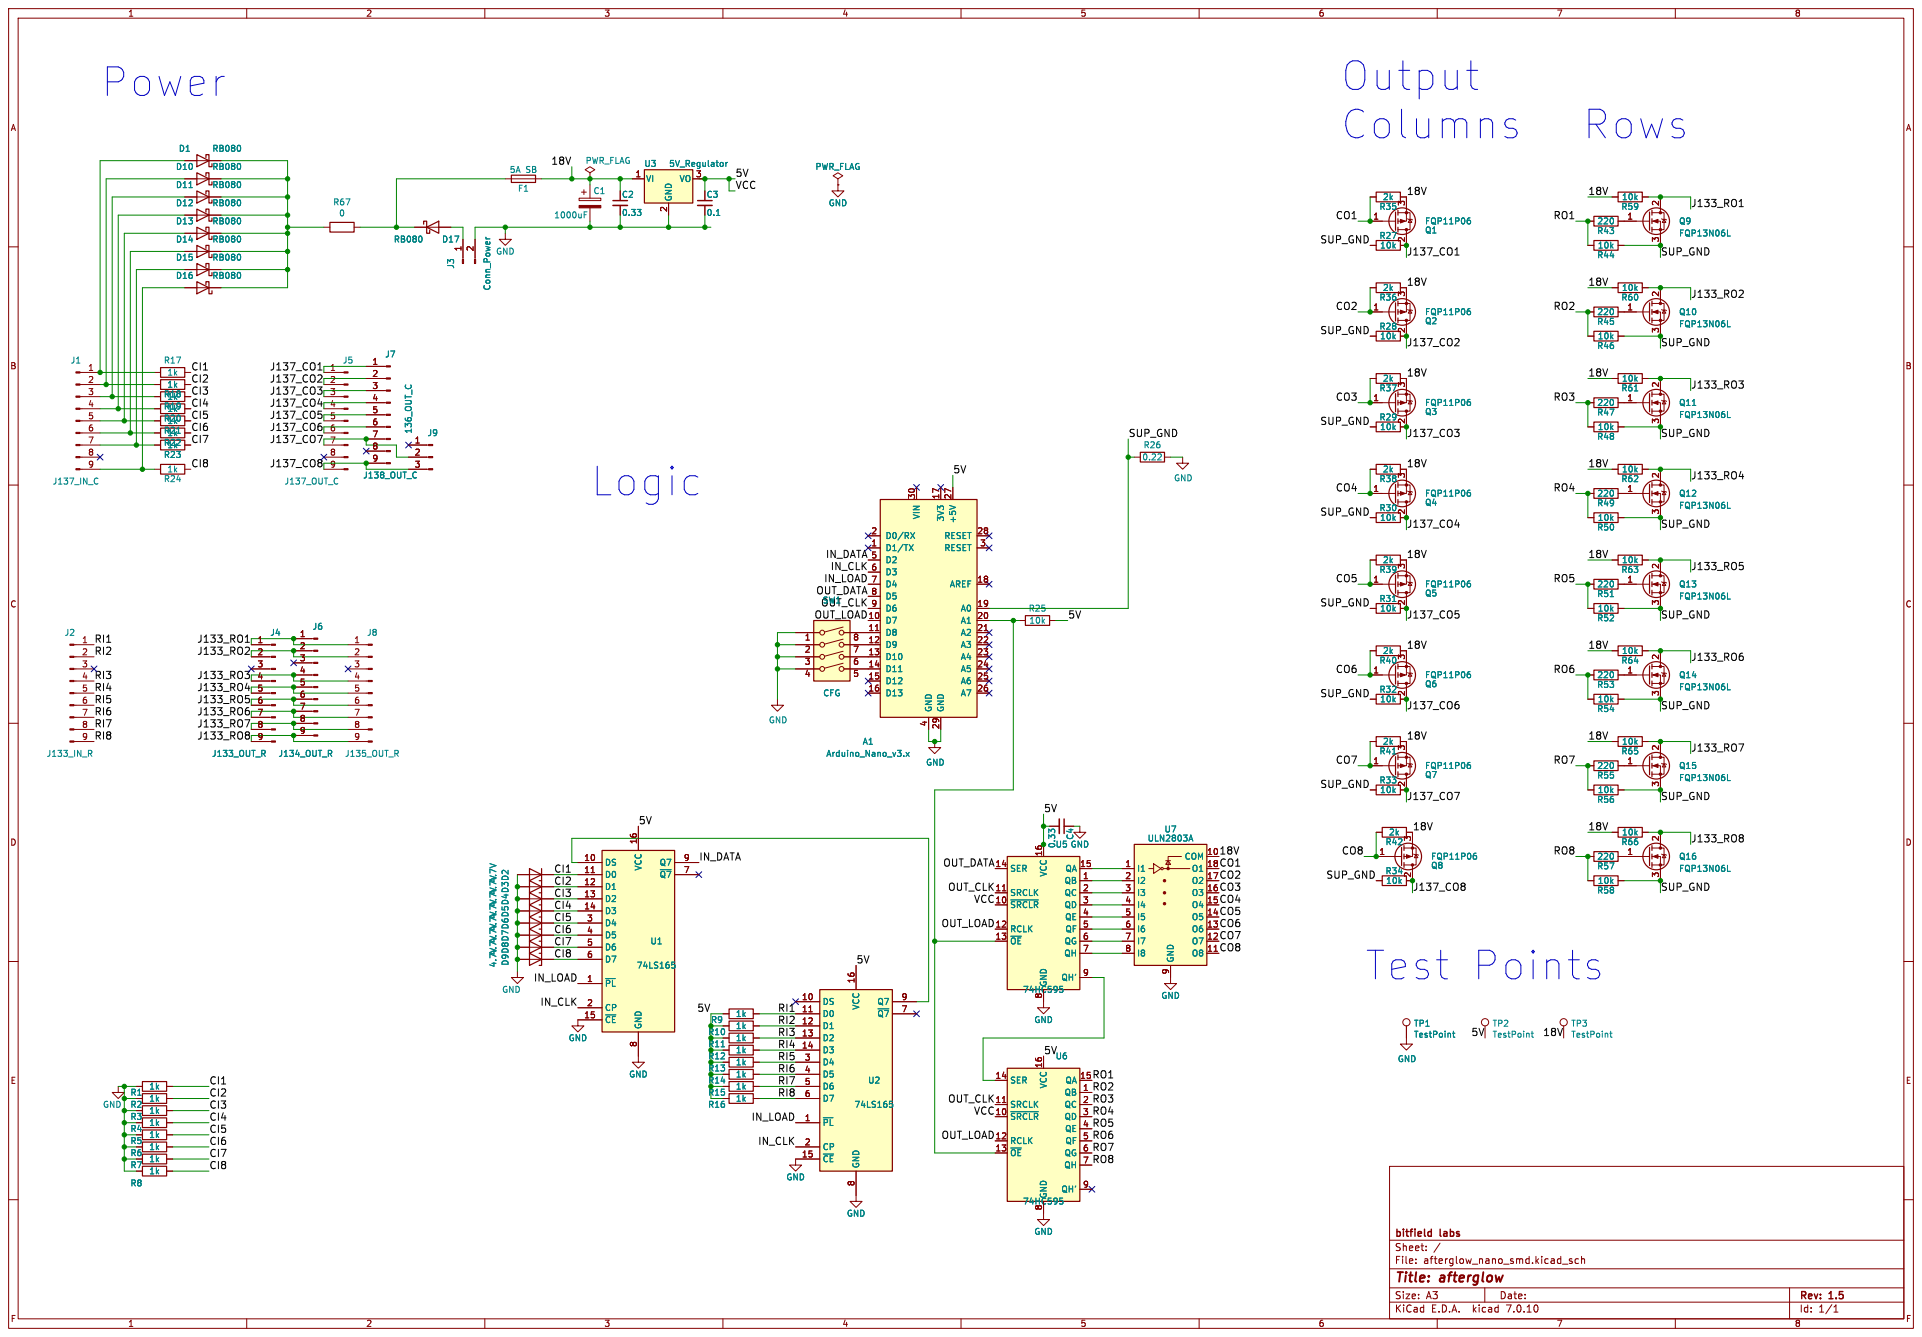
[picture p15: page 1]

4 D2 5 D3 6 D4 7 D5 8 D6 9 A1 Arduino_Nano_v3.x GND GND QB 1 ~{SRCLR} 10 SRCLK 11 RCLK 12 ~{OE} 13 SER 14 QA 15 VCC 16 QC 2 QD 3 QE 4 QF 5 QG 6 QH 7 GND

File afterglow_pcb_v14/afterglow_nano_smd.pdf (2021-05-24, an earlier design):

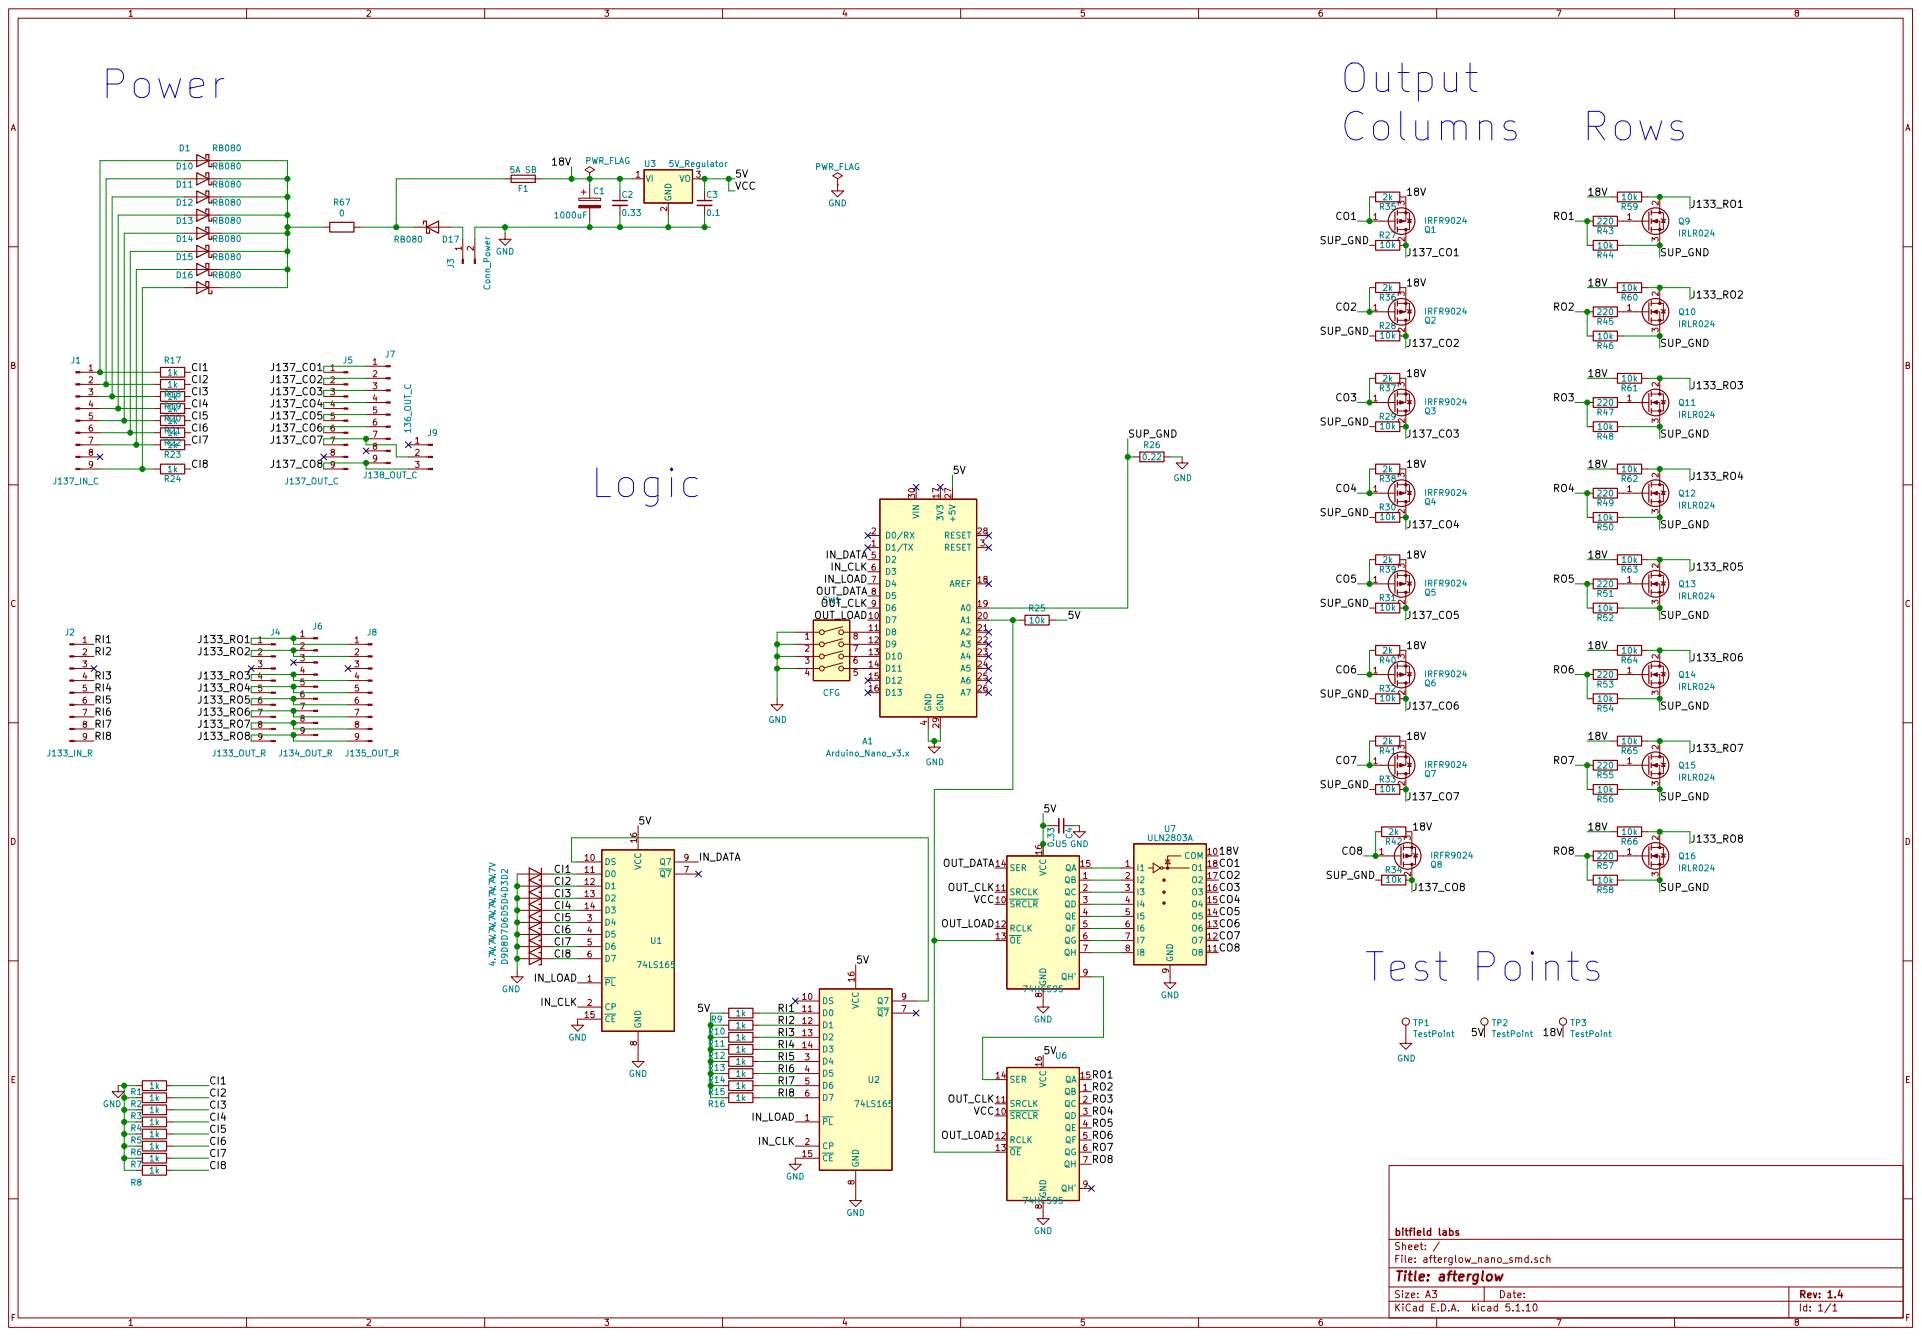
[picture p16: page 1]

CI3
CI4
CI5
CI6
CI7
CI8

File: afterglow_nano_smd.sch Sheet: / bitfield labs

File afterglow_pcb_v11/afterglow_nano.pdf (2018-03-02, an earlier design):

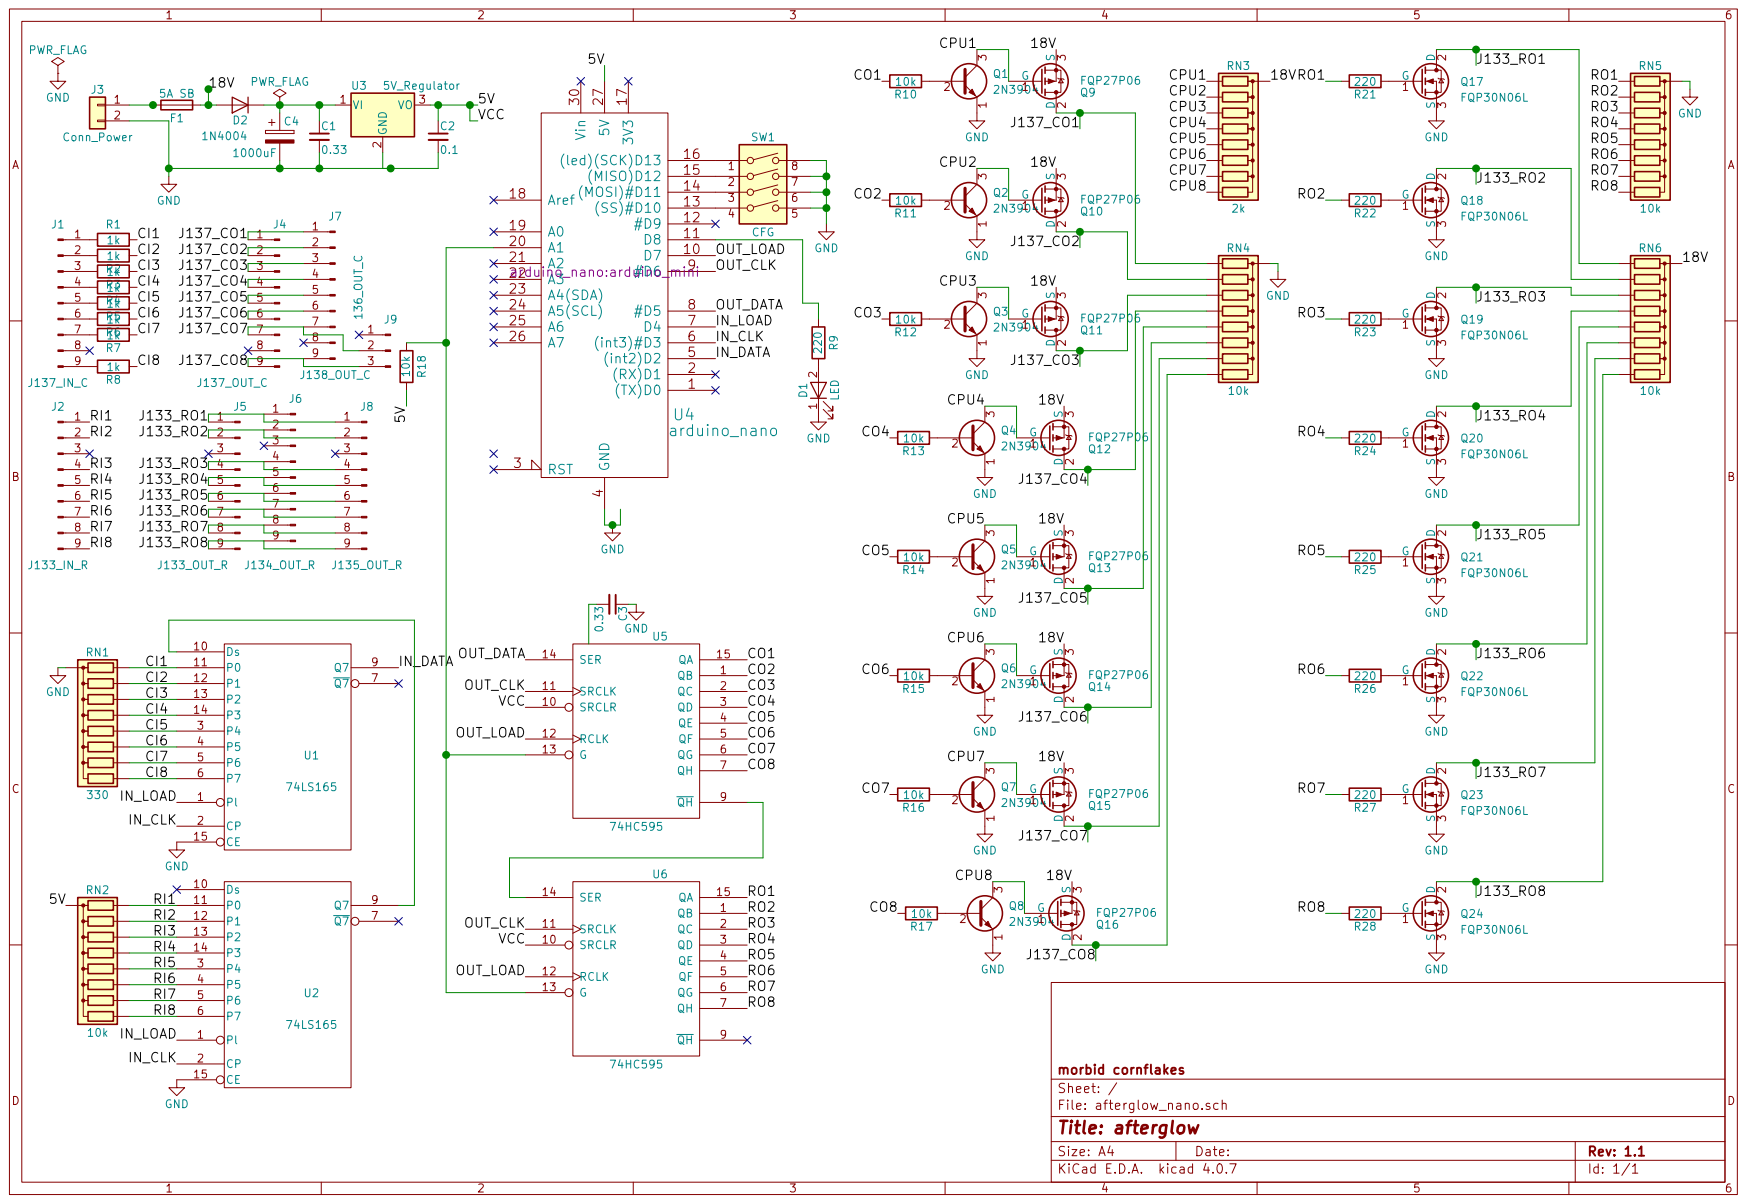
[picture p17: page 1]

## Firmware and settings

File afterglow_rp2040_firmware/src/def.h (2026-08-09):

/***********************************************************************
 *   ___  ___  ___  ___  ___  ___   _    ___  _ _ _ 
 *  | . || __>|_ _|| __>| . \/  _> | |  | . || | | |
 *  |   || _>  | | | _> |   /| <_/\| |_ | | || | | |
 *  |_|_||_|   |_| |___>|_\_\`____/|___|`___'|__/_/ 
 *                                                 rp2040
 *      Copyright (c) 2024 bitfield labs
 *
 ***********************************************************************
 *  This file is part of the afterglow pinball LED project:
 *  https://github.com/bitfieldlabs/afterglow
 *
 *  Licensed under the Apache License, Version 2.0 (the "License");
 *  you may not use this file except in compliance with the License.
 *  You may obtain a copy of the License at:
 *
 *  https://www.apache.org/licenses/LICENSE-2.0
 *
 * Unless required by applicable law or agreed to in writing, software
 * distributed under the License is distributed on an "AS IS" BASIS,
 * WITHOUT WARRANTIES OR CONDITIONS OF ANY KIND, either express or implied.
 * See the License for the specific language governing permissions and
 * limitations under the License.
 ***********************************************************************/

// Number of columns in the lamp matrix
#define NUM_COL 8

// Number of rows in the lamp matrix
#define NUM_ROW 10

// LED PWM frequency [Hz]
// This is the update frequency of each individual lamp.
// The maximum duty cycle for each update is 1/NUM_COL.
// This frequency will affect the achievable brightness, as for each column
// transition all output needs to be disabled briefly (ANTIGHOST_DURATION)
// in order to avoid ghosting. E.g., at 1kHz the update interval for one column
// is 125us (1ms / NUM_COL). 20us anti-ghosting duration will consume 16% of
// the available duty cycle. At a lower frequency of 400Hz the anti-ghosting
// only makes for 6% of the duty cycle, therefore the maximum achievable
// brightness is higher.
#define LED_FREQ 400

// PWM resolution (brightness steps)
// This is the number of duty cycle steps within one LED
// update interval (LED_FREQ).
// A higher resolution means longer data preparation and higher PIO
// frequency, but also smoother brightness steps.
// Valid resolutions: 4, 8, 16, 32, 64, 128, 256
#define PWM_RES 256
#define PWM_RES_MAX 256

// Lamp matrix update frequency [Hz]
// This is the frequency the output data is updated at.
// It should be high enough to allow for visually smooth transitions.
// Between updates the same data is repeatedly output at high rate
// (LED_FREQ * NUM_COL * PWM_RES).
#define MATRIX_UPDATE_FREQ 100

// Input sampling frequency [Hz]
// This is the frequency the input columns and rows are sampled at.
// It must be high enough to allow for multiple samples (SINGLE_UPDATE_CONS)
// of a single input data transition (2ms for WPC, 1ms for Whitestar).
#define INPUT_SAMPLING_FREQ 8000

// Number of consistent data samples required for matrix update. Helps prevent ghosting.
// The input sampling frequency (INPUT_SAMPLING_FREQ) must be high enough to
// produce enough samples for each original column duration (2ms for WPC, 1ms for Whitestar)
#define SINGLE_UPDATE_CONS 4

// Duration of anti ghosting [us] (turning off all lamps briefly)
// The rows are turned off for 2x this value, the columns only for 1x.
#define ANTIGHOST_DURATION 20

// Turn debug output via serial on/off
#define DEBUG_SERIAL 1

// Use an i2c OLED screen for debugging display
#define DEBUG_OLED_I2C 1

// Enable modding logic evaluation and output
#define MODDING_OUTPUT 0

// Afterglow RP2040 version number
#define AFTERGLOW_RP2040_VERSION 304

// Latest supported Afterglow board revision. Currently v3.0
#define BOARD_REV 30

//------------------------------------------------------------------------------
// Default afterglow setup

#define DEFAULT_GLOWDUR_ON        120     // Default glow duration turning on [ms]
#define DEFAULT_GLOWDUR_OFF       160     // Default glow duration turning on [ms]
#define DEFAULT_BRIGHTNESS          7     // Default maximum lamp brightness 0-7
#define DEFAULT_DELAY               0     // Default lamp delay [ms]


//------------------------------------------------------------------------------
// derived values
// ** DO NOT MODIFY **

// Input sampling interval time interval [us]
#define INPUT_SAMPLE_INT (1000000 / INPUT_SAMPLING_FREQ)

// Input sampling to matrix update ratio
#define SAMPLE_TO_UPDATE_RATIO (INPUT_SAMPLING_FREQ / MATRIX_UPDATE_FREQ)
// This ratio must be integer
#if ((SAMPLE_TO_UPDATE_RATIO * MATRIX_UPDATE_FREQ) != INPUT_SAMPLING_FREQ)
#error "The input sampling frequency must be an integer multiple of the matrix update frequency!"
#endif

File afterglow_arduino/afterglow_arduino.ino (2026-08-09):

/***********************************************************************
 *  afterglow:
 *      Copyright (c) 2018-2026 bitfield labs
 *
 ***********************************************************************
 *  This file is part of the afterglow pinball LED project:
 *  https://github.com/bitfieldlabs/afterglow
 *
 *  Licensed under the Apache License, Version 2.0 (the "License");
 *  you may not use this file except in compliance with the License.
 *  You may obtain a copy of the License at:
 *
 *  https://www.apache.org/licenses/LICENSE-2.0
 *
 * Unless required by applicable law or agreed to in writing, software
 * distributed under the License is distributed on an "AS IS" BASIS,
 * WITHOUT WARRANTIES OR CONDITIONS OF ANY KIND, either express or implied.
 * See the License for the specific language governing permissions and
 * limitations under the License.
 ***********************************************************************/
 
//------------------------------------------------------------------------------
/* This code assumes following pin layout:
 *
 *  +----------+---------------+-----------+---------------+--------------+
 *  | Name     | Function      | Nano Pin# | Register, Bit | Mode         |
 *  +----------+---------------+-----------+---------------+--------------+
 *  | IN_DATA  | 74LS165 Q_H   | D2        | DDRD, 2       | Input        |
 *  | IN_CLK   | 74LS165 CLK   | D3        | DDRD, 3       | Output       |
 *  | IN_LOAD  | 74LS165 LD    | D4        | DDRD, 4       | Output       |
 *  | OUT_DATA | 74HC595 SER   | D5        | DDRD, 5       | Output       |
 *  | OUT_CLK  | 74LS595 SRCLK | D6        | DDRD, 6       | Output       |
 *  | OUT_LOAD | 74LS595 RCLK  | D7        | DDRD, 7       | Output       |
 *  | OE       | 74LS595 OE    | A1        | DDRC, 1       | Output       |
 *  | R9_IN    | Row 9 IN (WS) | D12       | DDRB, 5       | Input Pullup |
 *  | R10_IN   | Row 10 IN (WS)| A4        | DDRC, 5       | Input Pullup |
 *  | R9_OUT   | Row 9 OUT (WS)| A2        | DDRC, 3       | Output       |
 *  | R10_OUT  | Row 10 OUT(WS)| A3        | DDRC, 4       | Output       |
 *  | TEST1    | TESTMODE 1    | D8        | DDRB, 1       | Input Pullup |
 *  | TEST2    | TESTMODE 2    | D9        | DDRB, 2       | Input Pullup |
 *  | TEST3    | TESTMODE 3    | D10       | DDRB, 3       | Input Pullup |
 *  | TEST4    | TESTMODE 4    | D11       | DDRB, 4       | Input Pullup |
 *  | CM       | CURRENT MEAS  | A0        | DDRC, 0       | Input        |
 *  | WS2812   | RGB LED (WS)  | A0        | DDRC, 0       | Output       |
 *  +----------+---------------+-----------+---------------+--------------+
*/

#include <EEPROM.h>
#include <avr/wdt.h>
#include <avr/boot.h>

//------------------------------------------------------------------------------
// Setup

#define AFTERGLOW_VERSION 110           // Afterglow version number
#define AFTERGLOW_WHITESTAR       0     // Enable Afterglow Whitestar mode (PCB version >=2.0) when set to 1
#define AFTERGLOW_BOARD_REV      15     // Latest supported Afterglow WPC/Sys11/DE board revision
#define AFTERGLOW_WS_BOARD_REV   21     // Latest supported Afterglow Whitestar/S.A.M. board revision
#define SINGLE_UPDATE_CONS        2     // Number of consistent data samples required for matrix update. Helps prevent ghosting.
#if AFTERGLOW_WHITESTAR
#  define TTAG_INT_A            200     // Matrix update time interval, config A [us]
#else
#  define TTAG_INT_A            150     // Matrix update time interval, config A [us]
#endif
#define TTAG_INT_B              250     // Matrix update time interval, config B [us]
#define PWM_STEPS_A               8     // Number of brightness steps, config A (only 4, 8 an 16 are currently supported)
#define PWM_STEPS_B               8     // Number of brightness steps, config B (only 4, 8 an 16 are currently supported)
#define ANTIGHOST_DURATION       20     // Duration of anti ghosting [us] (turning off all lamps briefly)
#define DEFAULT_GLOWDUR         140     // Default glow duration [ms]
#define DEFAULT_BRIGHTNESS        7     // Default maximum lamp brightness 0-7
#define CURRENT_MONITOR           0     // Monitor the current (unfinished featured, only on board rev >=1.3 and <2.0)   
#define DEBUG_SERIAL              0     // Turn debug output via serial on/off
#define REPLAY_ENABLED            0     // Enable lamp replay in test mode when set to 1
#define PROJECT_BUTTER            0     // Smooth as butter brightness transitions


//------------------------------------------------------------------------------
// Some definitions

// Afterglow configuration version
#if (AFTERGLOW_WHITESTAR == 0)
#  define AFTERGLOW_CFG_VERSION 1
#else
#  define AFTERGLOW_CFG_VERSION 2
#endif

// Afterglow board revision
#if (AFTERGLOW_WHITESTAR == 0)
#  define BOARD_REV AFTERGLOW_BOARD_REV
#else
#  define BOARD_REV AFTERGLOW_WS_BOARD_REV
#endif

// original matrix update interval [us]
#if (AFTERGLOW_WHITESTAR == 0)
#  define ORIG_INT (2000)
#else
#  define ORIG_INT (1000)
#endif

// cycles per original interval, config A
#define ORIG_CYCLES_A (ORIG_INT / TTAG_INT_A)

// cycles per original interval, config B
#define ORIG_CYCLES_B (ORIG_INT / TTAG_INT_B)

// number of columns in the lamp matrix
#define NUM_COL 8

// number of rows in the lamp matrix
#if (AFTERGLOW_WHITESTAR == 0)
#  define NUM_ROW 8
#else
#  define NUM_ROW 10
#endif

// number of strobed lines
#if (AFTERGLOW_WHITESTAR == 0)
// Most systems strobe the 8 columns
#  define NUM_STROBE NUM_COL
#  define NUM_NONSTROBE NUM_ROW
#else
// Stern Whitestar strobes the 10 rows
#  define NUM_STROBE NUM_ROW
#  define NUM_NONSTROBE NUM_COL
#endif

// glow duration scaling in the configuration
#define GLOWDUR_CFG_SCALE 10

#if (AFTERGLOW_WHITESTAR == 0)
// current supervision on pin A0
#  define CURR_MEAS_PIN A0
#else
// RGB status LED on A0
#  define RGB_LED_A0
#endif

// test mode setup
#define TEST_MODE_NUMMODES 7    // number of test modes
#define TEST_MODE_DUR 8         // test duration per mode [s]
#define TEST_MODE_DUR_CYCLES_A  ((uint32_t)TEST_MODE_DUR * 1000000UL / TTAG_INT_A) // number of cycles per testmode, config A
#define TEST_MODE_DUR_CYCLES_B  ((uint32_t)TEST_MODE_DUR * 1000000UL / TTAG_INT_B) // number of cycles per testmode, config B
#define TESTMODE_INT (500)      // test mode lamp switch interval [ms]
#define TESTMODE_CYCLES_A ((uint32_t)TESTMODE_INT * 1000UL / (uint32_t)TTAG_INT_A) // number of cycles per testmode interval, config A
#define TESTMODE_CYCLES_B ((uint32_t)TESTMODE_INT * 1000UL / (uint32_t)TTAG_INT_B) // number of cycles per testmode interval, config B

#if REPLAY_ENABLED
// Replay time scale [us]
#define REPLAY_TTAG_SCALE 16000

// Replay record
typedef struct AG_LAMP_SWITCH_s
{
    uint16_t col : 3;    // lamp column
    uint16_t row : 3;    // lamp row
    uint16_t dttag : 10; // delta time tag [16ms] to the last event
} AG_LAMP_SWITCH_t;

// Replay logic
byte replay(void);

// Number of replay records
int numReplays(void);
#endif // REPLAY_ENABLED


//------------------------------------------------------------------------------
// serial port protocol definition

// write buffer size [bytes]
#define AG_CMD_WRITE_BUF 32

// command terminator character
#define AG_CMD_TERMINATOR ':'

// version poll command string
#define AG_CMD_VERSION_POLL "AGV"

// configuration poll command string
#define AG_CMD_CFG_POLL "AGCP"

// configuration save command string
#define AG_CMD_CFG_SAVE "AGCS"

// configuration reset to default command string
#define AG_CMD_CFG_DEFAULT "AGCD"

// data ready string
#define AG_CMD_CFG_DATA_READY "AGDR"

// acknowledge string
#define AG_CMD_ACK "AGCACK"

// NOT acknowledge string
#define AG_CMD_NACK "AGCNACK"


//------------------------------------------------------------------------------
// Brightness maps

static const uint8_t skMap_256_4_log[256] PROGMEM =
{
    0,0,0,0,0,0,0,0,0,0,0,0,0,0,0,0,0,0,0,0,0,0,0,0,0,0,0,0,0,0,0,0,
    0,0,0,0,0,0,0,0,0,0,0,0,0,0,0,0,0,0,0,0,0,0,0,0,0,0,0,0,0,0,0,0,
    0,0,0,0,0,0,0,0,0,0,0,0,0,0,0,0,0,0,0,0,0,0,0,0,0,0,0,0,0,0,0,0,
    0,0,0,0,0,0,0,0,0,0,0,0,0,0,0,0,0,0,0,0,0,0,0,0,0,0,0,0,0,0,0,0,
    0,0,0,0,0,0,0,0,0,0,0,0,0,0,0,0,0,0,0,0,0,0,0,0,0,0,1,1,1,1,1,1,
    1,1,1,1,1,1,1,1,1,1,1,1,1,1,1,1,1,1,1,1,1,1,1,1,1,1,1,1,1,1,1,1,
    1,1,1,1,1,1,1,1,1,1,1,1,1,1,1,1,1,1,1,1,1,1,1,1,2,2,2,2,2,2,2,2,
    2,2,2,2,2,2,2,2,2,2,2,2,2,2,2,2,2,2,2,2,2,2,2,2,2,2,2,2,2,2,2,3
};

static const uint8_t skMap_256_8_log[256] PROGMEM =
{
    0,0,0,0,0,0,0,0,0,0,0,0,0,0,0,0,0,0,0,0,0,0,0,0,0,0,0,0,0,0,0,0,
    0,0,0,0,0,0,0,0,0,0,0,0,0,0,0,0,0,0,0,0,0,0,0,0,0,0,0,0,0,0,0,0,
    0,0,0,0,0,0,0,0,0,0,0,0,0,0,0,0,0,0,0,0,0,0,0,0,0,0,0,0,1,1,1,1,
    1,1,1,1,1,1,1,1,1,1,1,1,1,1,1,1,1,1,1,1,1,1,1,1,1,1,1,1,1,1,1,1,
    1,1,1,1,1,1,1,1,1,1,1,1,1,2,2,2,2,2,2,2,2,2,2,2,2,2,2,2,2,2,2,2,
    2,2,2,2,2,2,2,2,2,2,2,2,2,2,2,2,3,3,3,3,3,3,3,3,3,3,3,3,3,3,3,3,
    3,3,3,3,3,3,3,3,3,3,4,4,4,4,4,4,4,4,4,4,4,4,4,4,4,4,4,4,4,4,4,5,
    5,5,5,5,5,5,5,5,5,5,5,5,5,5,5,5,6,6,6,6,6,6,6,6,6,6,6,6,6,6,6,7
};

static const uint8_t skMap_256_16_log[256] PROGMEM =
{
    0,0,0,0,0,0,0,0,0,0,0,0,0,0,0,0,0,0,0,0,0,0,0,0,0,0,0,0,0,0,0,0,
    0,0,0,0,0,0,0,0,0,0,0,0,0,0,0,0,0,0,0,0,0,1,1,1,1,1,1,1,1,1,1,1,
    1,1,1,1,1,1,1,1,1,1,1,1,1,1,1,1,1,1,1,1,1,1,1,1,2,2,2,2,2,2,2,2,
    2,2,2,2,2,2,2,2,2,2,2,2,2,2,2,2,2,2,2,3,3,3,3,3,3,3,3,3,3,3,3,3,
    3,3,3,3,3,3,3,3,4,4,4,4,4,4,4,4,4,4,4,4,4,4,4,4,4,4,5,5,5,5,5,5,
    5,5,5,5,5,5,5,5,5,5,6,6,6,6,6,6,6,6,6,6,6,6,6,7,7,7,7,7,7,7,7,7,
    7,7,7,8,8,8,8,8,8,8,8,8,8,8,9,9,9,9,9,9,9,9,9,9,10,10,10,10,10,10,10,10,
    10,11,11,11,11,11,11,11,11,11,12,12,12,12,12,12,12,13,13,13,13,13,13,13,13,14,14,14,14,14,14,15
};

//------------------------------------------------------------------------------
// global variables

// Lamp matrix 'memory'
static uint16_t sMatrixState[NUM_COL][NUM_ROW];

#if PROJECT_BUTTER
// Step per matrix update for all lamps
static uint16_t sMatrixSteps[NUM_COL][NUM_ROW];
static bool sMatrixStepsDir[NUM_COL][NUM_ROW];

// Matrix value to brightness map
static const uint8_t *sBrightnessMap;
#endif

// local time
static uint32_t sTtag = 0;

// interrupt runtime counters [cycles]
static uint16_t sLastIntTime = 0;
static uint16_t sMaxIntTime = 0;
static volatile uint16_t sOverflowCount = 0;

// remember the last column and row samples
static uint16_t sLastColMask = 0;
static uint16_t sLastRowMask = 0;
static uint32_t sConsBadStrobeCounter = 0;

#if DEBUG_SERIAL
static uint16_t sLastOutColMask = 0;
static uint16_t sLastOutRowMask = 0;
static uint32_t sBadStrobeCounter = 0;
static uint32_t sBadStrobeOrderCounter = 0;
static uint16_t sLastBadStrobeMask = 0;
static uint8_t sLastGoodStrobeLine = 0;
#if CURRENT_MONITOR
static int sMaxCurr = 0;
static int sLastCurr = 0;
#endif
#endif

// afterglow configuration data definition
typedef struct AFTERGLOW_CFG_s
{
    uint16_t version;                         // afterglow version of the configuration
    uint16_t res;                             // reserved bytes
    uint8_t lampGlowDur[NUM_COL][NUM_ROW];    // Lamp matrix glow duration configuration [ms * GLOWDUR_CFG_SCALE]
    uint8_t lampBrightness[NUM_COL][NUM_ROW]; // Lamp matrix maximum brightness configuration (0-7)
    uint32_t crc;                             // data checksum
} AFTERGLOW_CFG_t;

// afterglow configuration
static AFTERGLOW_CFG_t sCfg;

// precalculated glow steps for each lamp
static uint16_t sGlowSteps[NUM_COL][NUM_ROW];

// precalculated maximum subcycle for lamp activation (brightness)
static byte sMaxSubcycle[NUM_COL][NUM_ROW];

// last state of PINB
static uint8_t sLastPINB = 0;

// status enumeration
typedef enum AFTERGLOW_STATUS_e
{
    AG_STATUS_INIT = 0,     // initialising
    AG_STATUS_OK,           // up and running
    AG_STATUS_PASSTHROUGH,  // ready in pass-through mode
    AG_STATUS_TESTMODE,     // ready in test mode
    AG_STATUS_REPLAY,       // ready in replay mode
    AG_STATUS_INVINPUT,     // invalid input
    AG_STATUS_OVERRUN       // interrupt overrun
} AFTERGLOW_STATUS_t;

// afterglow status
static AFTERGLOW_STATUS_t sStatus = AG_STATUS_INIT;
static AFTERGLOW_STATUS_t sLastStatus = AG_STATUS_INIT;


//------------------------------------------------------------------------------
// function prototypes

inline void updateMx(uint16_t *pMx, bool on, uint16_t step) __attribute__((always_inline));
inline uint8_t findSubCycle(uint16_t v) __attribute__((always_inline));


//------------------------------------------------------------------------------
void setup()
{
    noInterrupts(); // disable all interrupts

    // I/O pin setup
    // 74LS165 LOAD and CLK are output, DATA is input
    // 74HC595 LOAD, CLK and DATA are output
    DDRD = B11111001;
    // Whitestar row 9 on pin D12, testmode config on pins 8-11
    // Built-in LED on D13
    DDRB = B00100000;
    // activate the pullups for the testmode and the whitestar pins
    PORTB |= B00011111;
    // OE on A1, Whitestar on A2 and A3
    // current meas on A0 for AG <v2.0, WS2812 on AG >=v2.0
    DDRC = B00001110;
 #ifdef RGB_LED_A0
    // WS2812 RGB LED on pin A0
    DDRC |= B00000001;
 #endif
    // Whitestar row 10 pin on A4 (enable pullup)
    PORTC |= B00010000;
    // keep OE high
    PORTC |= B00000010;
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
void loop()
{
    // The main loop is used for low priority serial communication only.
    // All the lamp matrix fun happens in the timer interrupt.

    // count the loops (used for debug output below)
    static uint32_t loopCounter = 0;
    loopCounter++;

    // check for serial data
    static String cmd = "";
    static bool complete = false;
    while (Serial.available() && (complete == false))
    {
        char character = Serial.read();
        if (character != AG_CMD_TERMINATOR)
        {
            // add the character and wait for the command terminator
            cmd.concat(character);
        }
        else
        {
            // command complete
            complete = true;
        }
    }

    // handle complete commands
    if (complete)
    {
        // version poll
        if (cmd == AG_CMD_VERSION_POLL)
        {
            // Output the version numbers
            Serial.print(AG_CMD_VERSION_POLL);
            Serial.print(" ");
            Serial.print(AFTERGLOW_VERSION);
            Serial.print(" ");
            Serial.println(AFTERGLOW_CFG_VERSION);
        }

        // configuration poll
        else if (cmd == AG_CMD_CFG_POLL)
        {
            // send the full confiuration
            sendCfg();
        }

        // configuration reset
        else if (cmd == AG_CMD_CFG_DEFAULT)
        {
            // reset the configuration to default
            defaultCfg();
        }

        // configuration write
        else if (cmd == AG_CMD_CFG_SAVE)
        {
            // stop the matrix updates
            stop();

            // receive a new configuration
            receiveCfg();

            // resume operation
            start();
        }

        cmd = "";
        complete = false;
    }

    // watch out for interval configuration changes
    if ((PINB & B00000100) != (sLastPINB & B00000100))
    {
        // reinitialize the timers
        noInterrupts();
        timerSetup();
        sTtag = 0;
        sLastPINB = PINB;
        interrupts();
#if DEBUG_SERIAL
        Serial.print("New TTAG_INT: ");
        Serial.println((PINB & B00000100) ? TTAG_INT_A : TTAG_INT_B);
#endif
    }

#if DEBUG_SERIAL
    if ((loopCounter % 10) == 0)
    {
        // print the maximum interrupt runtime
        if ((PINB & B00000001) == 0)
        {
            Serial.println("TESTMODE!");
        }
        if ((PINB & B0000100) == 0)
        {
            Serial.println("REPLAY!");
        }
        if ((PINB & B0001000) == 0)
        {
            Serial.println("PASS THROUGH!");
        }
        Serial.print("TTAG_INT ");
        Serial.println((PINB & B00000100) ? TTAG_INT_A : TTAG_INT_B);
        Serial.print("INT dt max ");
        Serial.print(sMaxIntTime / 16);
        Serial.print("us last ");
        Serial.print(sLastIntTime / 16);
        Serial.print("us ovfl ");
        Serial.println(sOverflowCount);
        Serial.print("Bad col: ");
        Serial.print(sBadStrobeCounter);
        Serial.print(" col ");
        Serial.print(sLastBadStrobeMask);
        Serial.print(" ord ");
        Serial.print(sBadStrobeOrderCounter);
        Serial.print(" last good: ");
        Serial.println(sLastGoodStrobeLine);
#if CURRENT_MONITOR
        Serial.print("CM ");
        Serial.print(sLastCurr);
        Serial.print(" max ");
        Serial.println(sMaxCurr);
#endif
        // data debugging
        debugInputs(sLastColMask, sLastRowMask);
        debugOutput(sLastOutColMask, sLastOutRowMask);
        // dump the full matrix
        for (uint8_t c=0; c<NUM_COL; c++)
        {
            Serial.print("C");
            Serial.print(c);
            Serial.print(" + ");
            for (uint8_t r=0; r<NUM_ROW; r++)
            {
                Serial.print(sMatrixState[c][r]);
                Serial.print(" ");
            }
            Serial.println("");
        }
    }
#endif

    // wait 500ms
    delay(500);
}

#if PROJECT_BUTTER
//------------------------------------------------------------------------------
void updateOutCol(uint16_t outCol)
{
    // get a pointer to the matrix column
    uint16_t *pMx = &sMatrixState[outCol][0];
    uint16_t *pMxSt = &sMatrixSteps[outCol][0];
    bool *pMxStDir = &sMatrixStepsDir[outCol][0];

    for (uint8_t r=0; r<NUM_ROW; r++)
    {
        // update the matrix value
        updateMx(pMx, *pMxStDir, *pMxSt);

        // next row
        pMx++;
        pMxSt++;
        pMxStDir++;
    }
}
#endif

//------------------------------------------------------------------------------
inline void updateMx(uint16_t *pMx, bool on, uint16_t step)
{
    if (on)
    {
        // increase the stored brightness value
        uint16_t v = (*pMx + step);
        *pMx = (v < step) ? 0xffff : v;
    }
    else
    {
        // decrease the stored brightness value
        uint16_t v = (*pMx - step);
        *pMx = (v > step) ? 0 : v;
    }
}

//------------------------------------------------------------------------------
void updateCol(uint8_t col, uint16_t rowMask)
{
    // paranoia check
    if (col >= NUM_COL)
    {
        return;
    }

#if (PROJECT_BUTTER == 0)
    // get a pointer to the matrix column
    uint16_t *pMx = &sMatrixState[col][0];
    const uint16_t *pkStep = &sGlowSteps[col][0];

    // update all row values
    for (uint8_t r=0; r<NUM_ROW; r++)
    {
        // update the matrix value
        updateMx(pMx, (rowMask & 0x0001), *pkStep);

        // next row
        pMx++;
        pkStep++;
        rowMask >>= 1;
    }
#else
    // get a pointer to the matrix steps column
    uint16_t *pMxSt = &sMatrixSteps[col][0];
    bool *pMxStDir = &sMatrixStepsDir[col][0];
    const uint16_t *pkStep = &sGlowSteps[col][0];

    // update all row values
    for (uint8_t r=0; r<NUM_ROW; r++)
    {
        // set the matrix step value
        *pMxStDir = (rowMask & 0x0001);
        *pMxSt = *pkStep;

        // next row
        pMxSt++;
        pMxStDir++;
        pkStep++;
        rowMask >>= 1;
    }
#endif
}

//------------------------------------------------------------------------------
void updateRow(uint8_t row, uint16_t colMask)
{
    // paranoia check
    if (row >= NUM_ROW)
    {
        return;
    }

#if (PROJECT_BUTTER == 0)
    // get a pointer to the matrix row
    uint16_t *pMx = &sMatrixState[0][row];
    const uint16_t *pkStep = &sGlowSteps[0][row];

    // update all column values
    for (uint8_t c=0; c<NUM_COL; c++)
    {
        // update the matrix value
        updateMx(pMx, (colMask & 0x0001), *pkStep);

        // next row
        pMx += NUM_ROW;
        pkStep += NUM_ROW;
        colMask >>= 1;
    }
#else
    // get a pointer to the matrix row
    uint16_t *pMxSt = &sMatrixSteps[0][row];
    bool *pMxStDir = &sMatrixStepsDir[0][row];
    const uint16_t *pkStep = &sGlowSteps[0][row];

    // update all column values
    for (uint8_t c=0; c<NUM_COL; c++)
    {
        // update the matrix step value
        *pMxStDir = (colMask & 0x0001);
        *pMxSt = *pkStep;

        // next row
        pMxSt += NUM_ROW;
        pMxStDir += NUM_ROW;
        pkStep += NUM_ROW;
        colMask >>= 1;
    }
#endif
}

//------------------------------------------------------------------------------
void updateStrobe(uint8_t strobe, uint16_t colMask, uint16_t rowMask)
{
#if (AFTERGLOW_WHITESTAR == 0)
    updateCol(strobe, rowMask);
#else
    updateRow(strobe, colMask);
#endif
}
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

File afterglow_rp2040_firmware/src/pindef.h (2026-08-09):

/***********************************************************************
 *   ___  ___  ___  ___  ___  ___   _    ___  _ _ _ 
 *  | . || __>|_ _|| __>| . \/  _> | |  | . || | | |
 *  |   || _>  | | | _> |   /| <_/\| |_ | | || | | |
 *  |_|_||_|   |_| |___>|_\_\`____/|___|`___'|__/_/ 
 *                                                 rp2040
 *      Copyright (c) 2024 bitfield labs
 *
 ***********************************************************************
 *  This file is part of the afterglow pinball LED project:
 *  https://github.com/bitfieldlabs/afterglow
 *
 *  Licensed under the Apache License, Version 2.0 (the "License");
 *  you may not use this file except in compliance with the License.
 *  You may obtain a copy of the License at:
 *
 *  https://www.apache.org/licenses/LICENSE-2.0
 *
 * Unless required by applicable law or agreed to in writing, software
 * distributed under the License is distributed on an "AS IS" BASIS,
 * WITHOUT WARRANTIES OR CONDITIONS OF ANY KIND, either express or implied.
 * See the License for the specific language governing permissions and
 * limitations under the License.
 ***********************************************************************/

//------------------------------------------------------------------------------
/* This code assumes following RP2040 pin layout:
 *
 *  +------------+-----------------+------------+-----------+
 *  | Name       | Function        | Pico Pin#  | Mode      |
 *  +------------+-----------------+------------+-----------+
 *  | CO1-CO8    | Column Output   | GPIO 0-7   | OUTPUT    |
 *  | RO1-RO10   | Row Output      | GPIO 8-17  | OUTPUT    |
 *  | OUT_CLK    | OUT SR Clock    | GPIO 20    | OUTPUT    |
 *  | OUT_DATA   | OUT SR Data     | GPIO 21    | OUTPUT    |
 *  | OUT_LOAD   | OUT SR Latch    | GPIO 22    | OUTPUT    |
 *  | IN_CLK     | IN SR Clock     | GPIO 23    | OUTPUT    |
 *  | IN_DATA    | IN SR Data      | GPIO 24    | INPUT     |
 *  | IN_LOAD    | IN SR Latch     | GPIO 25    | OUTPUT    |
 *  | STAT_LED   | Status LED      | GPIO 27    | OUTPUT    |
 *  | D_SCL      | Display SCL     | GPIO 28    | OUTPUT    |
 *  | D_SDA      | Display SDA     | GPIO 29    | OUTPUT    |
 *  +------------+-----------------+------------+-----------+
*/

#include <stdio.h>

#define NUM_COL_PINS     8             // Number of column pins
#define NUM_ROW_PINS    10             // Number of row pins

// Input
#define AGPIN_IN_DATA   24             // Shift register input data

// Output
#define AGPIN_CO1        0             // Column 1 output
#define AGPIN_CO2        1             // Column 2 output
#define AGPIN_CO3        2             // Column 3 output
#define AGPIN_CO4        3             // Column 4 output
#define AGPIN_CO5        4             // Column 5 output
#define AGPIN_CO6        5             // Column 6 output
#define AGPIN_CO7        6             // Column 7 output
#define AGPIN_CO8        7             // Column 8 output

#define AGPIN_RO1        8             // Row 1 output
#define AGPIN_RO2        9             // Row 2 output
#define AGPIN_RO3       10             // Row 3 output
#define AGPIN_RO4       11             // Row 4 output
#define AGPIN_RO5       12             // Row 5 output
#define AGPIN_RO6       13             // Row 6 output
#define AGPIN_RO7       14             // Row 7 output
#define AGPIN_RO8       15             // Row 8 output
#define AGPIN_RO9       16             // Row 9 output
#define AGPIN_RO10      17             // Row 10 output

#define AGPIN_OUT_CLK   20             // Output shift register clock
#define AGPIN_OUT_DATA  21             // Output shift register data
#define AGPIN_OUT_LOAD  22             // Output shift register latch

#define AGPIN_IN_CLK    23             // Input shift register clock
#define AGPIN_IN_LOAD   25             // Input shift register latch

#define AGPIN_STAT_LED  27             // Status LED

#define AGPIN_D_SCL     28             // Display SCL
#define AGPIN_D_SDA     29             // Display SDA

//------------------------------------------------------------------------------
// utility macros

#define AGPIN_OUT_ALL_MASK ((1 << AGPIN_CO1) | (1 << AGPIN_CO2) | (1 << AGPIN_CO3) | (1 << AGPIN_CO4) | \
                            (1 << AGPIN_CO5) | (1 << AGPIN_CO6) | (1 << AGPIN_CO7) | (1 << AGPIN_CO8) | \
                            (1 << AGPIN_RO1) | (1 << AGPIN_RO2) | (1 << AGPIN_RO3) | (1 << AGPIN_RO4) | \
                            (1 << AGPIN_RO5) | (1 << AGPIN_RO6) | (1 << AGPIN_RO7) | (1 << AGPIN_RO8) | \
                            (1 << AGPIN_RO9) | (1 << AGPIN_RO10))

#define AGPIN_OUT_COL_MASK ((1 << AGPIN_CO1) | (1 << AGPIN_CO2) | (1 << AGPIN_CO3) | (1 << AGPIN_CO4) | \
                            (1 << AGPIN_CO5) | (1 << AGPIN_CO6) | (1 << AGPIN_CO7) | (1 << AGPIN_CO8))


extern const uint8_t skAGColOutPins[NUM_COL_PINS];
extern const uint8_t skAGRowOutPins[NUM_ROW_PINS];

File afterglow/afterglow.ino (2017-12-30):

/***********************************************************************
 *  afterglow:
 *      Copyright (c) 2017 Christoph Schmid
 *
 ***********************************************************************
 *  This file is part of the afterglow pinball LED project:
 *
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
 *  You should have received a copy of the GNU Lesser General Public
 *  License along with afterglow.
 *  If not, see <http://www.gnu.org/licenses/>.
 ***********************************************************************/
 
//------------------------------------------------------------------------------
/* This script assumes following pin layout:
 *
 *  +----------+---------------+-----------+---------------+--------------+
 *  | Name     | Function      | Nano Pin# | Register, Bit | Mode         |
 *  +----------+---------------+-----------+---------------+--------------+
 *  | IN_DATA  | 74LS165 Q_H   | D2        | DDRD, 2       | Input        |
 *  | IN_CLK   | 74LS165 CLK   | D3        | DDRD, 3       | Output       |
 *  | IN_LOAD  | 74LS165 LD    | D4        | DDRD, 4       | Output       |
 *  | OUT_DATA | 74HC595 SER   | D5        | DDRD, 5       | Output       |
 *  | OUT_CLK  | 74LS595 SRCLK | D6        | DDRD, 6       | Output       |
 *  | OUT_LOAD | 74LS595 RCLK  | D7        | DDRD, 7       | Output       |
 *  | LED      | LED           | A0        | DDRC, 0       | Output       |
 *  | OE       | 74LS595 OE    | A1        | DDRC, 1       | Output       |
 *  | DBG      | DEBUG         | A2        | DDRC, 2       | Output       |
 *  | CFG0     | DIP CFG 0     | D10       | DDRB, 2       | Input Pullup |
 *  | CFG1     | DIP CFG 1     | D11       | DDRB, 3       | Input Pullup |
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

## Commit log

2017-12-30 afterglow v1.0
    [afterglow_nano.kicad_pcb, afterglow_nano.sch]
2017-12-30 v1.1 schematic preparations
    [afterglow_nano.sch]
2017-12-30 + gerber files for v1.0
    [afterglow_nano-B.Cu.gbl, afterglow_nano-B.Mask.gbs, afterglow_nano-B.SilkS.gbo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]
2017-12-31 v1.1 progress
    [afterglow_nano.kicad_pcb, afterglow_nano.sch]
2017-12-31 v1.1 PCB
    [afterglow_nano.kicad_pcb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]
2018-01-06 Minor trace fix
    [afterglow_nano.kicad_pcb]
2018-01-12 Finalized v1.1 PCB
    [afterglow_nano.kicad_pcb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]
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2018-01-28 Added SMD layout by marcus_m
    [afterglow_nano_smd.kicad_pcb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]
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2018-02-02 PCB v1.2 SMD by Marcus
    [afterglow_nano_smd.kicad_pcb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]
2018-02-11 Fixed the register bit numbers
    [afterglow_arduino.ino]
2018-02-21 RN1 value change
    [afterglow_nano.sch]
2018-02-25 Avoid division by zero
    [afterglow_arduino.ino]
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2018-03-03 Drive the lamps at the beginning of the interrupt
    This avoids irrgular update frequencies due to varying update calculation times
    [afterglow_arduino.ino]
2018-03-03 Inverted glow duration configuration pins and switched interval to 75ms
    [afterglow_arduino.ino]
2018-03-10 Fixed a stupid mistake
    [afterglow_arduino.ino]
2018-03-11 Added a reset configuration to default function
    [afterglow_arduino.ino]
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2018-09-23 SMD version 1.3 preparations
    [afterglow_nano_smd.sch]
2018-09-23 FW upload preparations
    [afterglow_nano_smd.sch]
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2018-09-28 v1.3 PCB progress
    [afterglow_nano_smd.kicad_pcb, afterglow_nano_smd.sch]
2018-09-29 v1.3 progressing
    [afterglow_nano_smd.kicad_pcb, afterglow_nano_smd.sch]
2018-09-29 PCB complete
    [afterglow_nano_smd.kicad_pcb]
2018-09-29 Some 3d shape updates
    [afterglow_nano_smd.kicad_pcb]
2018-10-05 Added the configuration DIP switch back - it might be handy after all
    [afterglow_nano_smd.kicad_pcb, afterglow_nano_smd.sch]
2018-10-07 PCB v1.3 ready
    [afterglow_nano_smd.kicad_pcb]
2018-10-07 3d zuex
    [afterglow_nano_smd.kicad_pcb]
2018-10-15 Added input Zener diodes
    [afterglow_nano_smd.kicad_pcb, afterglow_nano_smd.sch]
2018-10-27 Update v1.3 Gerber files
    [afterglow_nano_smd-B.Cu.gbl, afterglow_nano_smd-B.Mask.gbs, afterglow_nano_smd-B.SilkS.gbo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]
2018-10-28 Deleted the measures
    [afterglow_nano_smd.kicad_pcb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]
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2018-11-11 Minor schematic updates
    [afterglow_nano_smd.sch]
2018-11-16 The row pullups must be 1k instead of 10k. Other minor adjustments.
    [afterglow_nano_smd.kicad_pcb, afterglow_nano_smd.sch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]
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2019-10-04 Fixed a stupid C mistake
    [afterglow_arduino_exp.ino]
2020-06-07 New stern sam schematic proposal
    [afterglow_nano_smd_stern_sam.sch]
2020-06-07 Moved Stern SAM stuff to a development branch
    [afterglow_nano_smd_stern_sam.sch]
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2021-05-24 Explicit PCB versions
    [afterglow_nano.kicad_pcb, afterglow_nano.sch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]
2021-05-24 PCB v1.4
    [afterglow_nano_smd.kicad_pcb, afterglow_nano_smd.sch]
2021-05-24 Some schematics update
    [afterglow_nano_smd.sch]
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2022-01-02 Fixed some PCB silkscrening issues
    [afterglow_nano_smd.kicad_pcb]
2022-01-09 Preparing the Whitestar PCB
    [afterglow_nano_smd.kicad_pcb, afterglow_nano_smd.sch]
2022-01-13 Kicad 6
    [afterglow_nano_smd.kicad_pcb, afterglow_nano_smd.sch]
2022-01-14 Layout experiments
    [afterglow_nano_smd.kicad_pcb]
2022-01-21 Some progress
    [afterglow_nano_smd.kicad_pcb]
2022-01-21 More progress
    [afterglow_nano_smd.kicad_pcb]
2022-01-23 Some renaming
    [afterglow_nano_smd.sch, afterglow_whitestar.kicad_sch, afterglow_whitestar_bom_jlc.csv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]
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2022-02-13 Whitestar PCB v2.1
    [afterglow_whitestar.kicad_sch, afterglow_whitestar_bom_jlc.csv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]
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2022-02-22 Fixed a Whitestar brightness computation mistake
    [afterglow_arduino.ino]
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2022-02-26 PCB version 1.5
    [afterglow_nano_smd.kicad_sch]
2022-03-13 Added JLCPCB production files
    [afterglow_nano_smd.kicad_sch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]
2022-06-18 Added missing JLCPCB file
    [afterglow_nano_smd_bom_jlc.csv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]
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2023-03-03 Fixed a wrong debug counter
    [afterglow_arduino.ino]
2024-02-09 En Afang
    [afterglow.kicad_sch]
2024-02-19 Schematic progress2
    [afterglow.kicad_pcb, afterglow.kicad_sch]
2024-02-20 Better parts
    [afterglow.kicad_sch]
2024-02-20 Better parts, part 2
    [afterglow.kicad_sch]
2024-02-20 Better parts, part 3
    [afterglow.kicad_sch]
2024-02-21 Better parts, part 4
    [afterglow.kicad_sch]
2024-02-22 Bald fettig
    [afterglow.kicad_sch]
2024-02-22 Schema isch bald fettig
    [afterglow.kicad_pcb, afterglow.kicad_sch]
2024-02-22 PCB go!
    [afterglow.kicad_pcb, afterglow.kicad_sch]
2024-02-23 PCB progress
    [afterglow.kicad_pcb]
2024-02-23 Placement starting
    [afterglow.kicad_pcb, afterglow.kicad_sch]
2024-02-23 Placement progressing
    [afterglow.kicad_pcb]
2024-02-23 Placement of input section done
    [afterglow.kicad_pcb]
2024-02-23 Some routing
    [afterglow.kicad_pcb, afterglow.kicad_sch]
2024-02-23 Better hat
    [afterglow.kicad_pcb, afterglow.kicad_sch]
2024-02-23 Output layout
    [afterglow.kicad_pcb]
2024-02-23 Output routing
    [afterglow.kicad_pcb]
2024-02-24 Last version with output shift registers
    [afterglow.kicad_pcb]
2024-02-24 Input shift registers, direct output
    [afterglow.kicad_pcb, afterglow.kicad_sch]
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2024-02-25 Pico routing, die zwoote
    [afterglow.kicad_pcb]
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2024-04-07 v3.0f: Some schematic fixes
    [afterglow.kicad_sch]
2024-04-07 Preparing for PCB update v3.0f
    [afterglow.kicad_sch]
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2024-04-12 Moved the production files
    [afterglow_bom_jlc.csv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]
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2024-04-14 JLC processing fixes
    [afterglow.kicad_sch, afterglow_bom_jlc.csv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]
2024-04-14 Using a 470uF capacitor
    [afterglow.kicad_sch, afterglow_bom_jlc.csv]
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2024-04-26 Removed wrong pin headers from production files
    [hat_debug.kicad_sch, hat_debug_bom_jlc.csv]
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2024-04-30 Inverted DIP switch logic
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2024-05-26 Fixed debug hat
    [hat_debug.kicad_sch, hat_debug_bom_jlc.csv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]
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2024-05-26 Hat i2c pinout fix
    [hat_template.kicad_sch]
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2024-05-26 Added production DIP switch
    [afterglow.kicad_sch, afterglow_bom_jlc.csv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]
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2024-05-26 Added i2c pullup resistors
    [hat_debug.kicad_sch, hat_debug_bom_jlc.csv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]
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2024-09-06 Pinbender hat v1.1. Fixes a short of the I2C to ground.
    [hat_stern_de_sys11.kicad_sch]
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2024-12-08 Added some 3D print holder models
    [ag_14_to_30_holder_wpc_insert.stl, ag_14_to_30_holder_wpc_screw.stl]
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2025-01-05 Fixed wrong input connector labels
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2025-03-28 Added missing source files
    [params.c]
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2026-01-02 Safer (24V) 1117 variant
    [afterglow_bom_jlc.csv]
2026-08-09 Faster switching with lower pull-down resistors
    [afterglow.kicad_sch]
2026-08-09 Safer LDO with voltage range up to 24V
    [afterglow.kicad_sch]
2026-08-09 Relicense software to Apache-2.0 and hardware to CERN-OHL-P-2.0
    - Firmware and configuration software are licensed under Apache-2.0.
    - Hardware designs are licensed under CERN-OHL-P-2.0.
    All contributors with copyrightable contributions
    have consented to the relicensing, or their
    contributions have been replaced.
    [afterglow.c, afterglow_arduino.ino, afterglow_arduino_exp.ino]
